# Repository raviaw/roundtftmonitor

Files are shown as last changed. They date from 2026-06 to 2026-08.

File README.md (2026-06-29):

# roundtftmonitor

A desk **PC + Claude usage monitor** on a 1.28″ round ESP32 display
(GUITION **ESP32-2424S012**, ESP32-C3 + GC9A01 + CST816 touch).

Two touch-paged screens:

- **PC** — outer ring = **CPU %**, inner ring = **RAM %**, with the live numbers
  in the middle. Thin outer rings hint the Claude session/week.
- **Claude** — outer ring = **5-hour session %**, inner = **7-day week %**, each
  with a **period-progress bar** and **time-left** label (e.g. `2h left`, `7d left`).
  Thin outer rings hint CPU/RAM.

Colors are green < 60 %, amber 60–85 %, red > 85 %. A small white tick marks each
gauge's 0/start. **Short tap** switches pages; **long-press (>0.6 s)** rotates 90°.

> Heads-up: the Claude session/week figures come from an **undocumented**
> endpoint (see [Claude usage](#claude-usage)); it can change or break without notice.

## How it works

```
 Windows host (host/pc_monitor.py)            ESP32-2424S012 (firmware/monitor)
 ─ reads CPU%/RAM% (psutil)                    ─ parses "key=value" serial lines
 ─ reads Claude session/week % + hours-left    ─ draws two ring-gauge pages
   from the OAuth usage endpoint        ──USB──▶  (touch: tap=page, long=rotate)
 ─ streams one line/sec over COM5 @115200
```

Example line: `cpu=37.5 ram=61.2 sess=26 week=56 sessp=44 weekp=99 sessh=2.8 weekh=8`

## Hardware

| Function | GPIO | | Function | GPIO |
|---|---|---|---|---|
| LCD SCLK | 6 | | Touch SDA (I²C) | 4 |
| LCD MOSI | 7 | | Touch SCL (I²C) | 5 |
| LCD DC | 2 | | Touch INT | 0 |
| LCD CS | 10 | | Touch RST | 1 |
| LCD backlight | 3 | | BOOT button | 9 |
| LCD RST | tied to chip reset | | GPIO 8 | free |

ESP32-C3 (RISC-V @160 MHz, Wi-Fi+BLE5, 4 MB flash, native USB-Serial/JTAG),
GC9A01 240×240 round IPS, CST816D touch (I²C 0x15), no IMU. Full identification:
[`roundtft-hardware.md`](roundtft-hardware.md).

## Build & flash (firmware)

Uses **arduino-cli** + the ESP32 core + **LovyanGFX**.

```sh
FQBN=esp32:esp32:esp32c3:CDCOnBoot=cdc,FlashSize=4M   # CDCOnBoot=cdc is required
arduino-cli compile --fqbn $FQBN --build-path firmware/monitor/build firmware/monitor
arduino-cli upload  -p COM5 --fqbn $FQBN --input-dir firmware/monitor/build firmware/monitor
```

Stop the host agent before flashing (it holds COM5). To restore the as-shipped
GUITION demo: `esptool --port COM5 write-flash 0x0 backup-firmware-stock-4MB.bin`.

## Host agent

```sh
pip install pyserial psutil
python host/pc_monitor.py        # auto-detects the board's COM port
```

CPU%/RAM% come from plain perf counters (no driver, no admin) and update every
second; Claude usage is polled every 5 minutes. To start it automatically at logon,
run `host/install-startup.ps1` once. See [`host/README.md`](host/README.md) for
autostart management and cable/port troubleshooting.

## Claude usage

Session/week % and time-left are read from the **undocumented**
`GET https://api.anthropic.com/api/oauth/usage` using the OAuth token Claude Code
stores in `~/.claude/.credentials.json` (`five_hour` / `seven_day` utilization +
`resets_at`). There is no official API for this; the endpoint may change or break.

## 3D-printed tilt stand

Parametric angled cradle in [`stand/`](stand/) (`stand.scad` → `stand.stl`).
Verify `disc_d` / `disc_t` with calipers first. See [`stand/README.md`](stand/README.md).

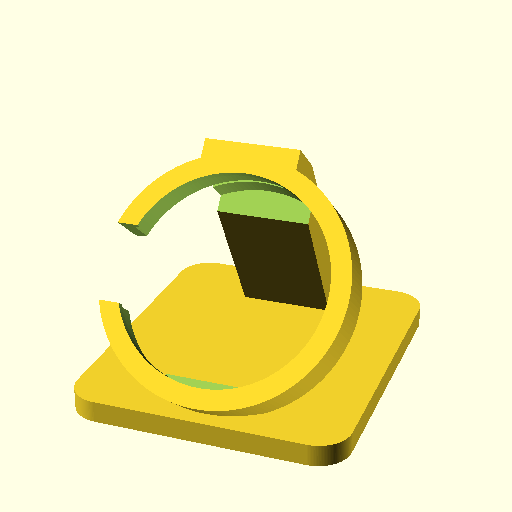
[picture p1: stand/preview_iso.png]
Tilt stand render


## Repo layout

| Path | What |
|---|---|
| `firmware/monitor/` | the monitor sketch (flash this) |
| `firmware/probe/`, `firmware/i2cscan/` | bring-up helpers (pin test, I²C scan) |
| `host/` | Windows serial agent + launcher |
| `stand/` | OpenSCAD tilt stand + renders |
| `PROJECT.md` | design notes, decisions, status |
| `CLAUDE.md` | operational notes & gotchas |
| `roundtft-hardware.md` | chip/board identification |
| `backup-firmware-stock-4MB.bin` | as-shipped firmware (restore point) |

---
🤖 Built with [Claude Code](https://claude.com/claude-code).

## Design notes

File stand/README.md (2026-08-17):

# Desk tilt-stand for the round display

Custom angled cradle for the GUITION **ESP32-2424S012** (1.28" round, ESP32-C3),
sized for the unit **in the plastic shell it ships in** — not a bare PCB.
No off-the-shelf round-board tilt stand exists, so this is a parametric design.

## Files
- `stand.scad` — parametric source (edit + re-render in OpenSCAD)
- `gcode/stand_K1Max_PLA_0.20mm.gcode` — **sliced and ready to print**
- `stand_K1Max_project.3mf` — **the profile, portable**: model + every setting,
  opens ready to slice in Creality Print / Creality Opus / OrcaSlicer
- `stand.3mf` — plain geometry, no settings; 3MF carries units so it imports at
  the right size and orientation
- `slice.sh` + `slicer/*.json` — how that G-code is produced
- `stand.stl` — same mesh, for anything that wants STL
- `verify.py` + `verify.scad` — **run after any change**; ten pass/fail checks
- `gcode_check.py` — bounds-checks sliced G-code and proves the brim is real
- `print_check.py` — build-volume fit, overhang and bed-contact numbers
- `preview_iso.png` / `preview_side.png` / `preview_front.png` — renders
- `fit_check.png` — the shell drawn seated in the cradle (see below)
- `drawing.html` — a single-file drawing sheet: dimensioned section through the
  seat, all views, the dimension schedule and the fit-check results
- `page.tpl.html` + `build_page.py` + `views/` — how `drawing.html` is generated

## The drawing sheet
`drawing.html` is self-contained — every view is inlined as a data URI, because
it gets published as an Artifact and that CSP blocks all external hosts. Rebuild
it with:

```
python build_page.py            # reuse views/
python build_page.py --render   # re-render every view first (~3 min)
```

Both grounds are rendered (`Cornfield` / `Tomorrow Night`) and the page swaps
them with the viewer's theme, so edit `CAMERAS` in `build_page.py` rather than
adding one-off renders.

## What it holds
The shell is a rounded **pebble**, not a cylinder: **45 mm** across at its widest
(its equator), **11 mm** thick, domed glass front, flat-ish back, and the
**USB-C port on the rim**. The black glass is **42 mm**, leaving only **1.5 mm**
of plastic rim — that rim is the entire ledge the cradle has to grip.

> An earlier 40.5 mm figure for the outer edge was wrong and everything derived
> from it was undersized. 45/42 are the measured values.

## What it is
A ring cradle leaning back **38°** toward a seated viewer, on a rearward base
with a back leg. Single solid piece, prints flat on the base.

The seat is a **straight bore plus a front lip**. The shell drops in from the
**back** and stops when its face meets the lip; the backward lean means gravity
presses it onto that lip, so nothing needs to snap or clamp and it still lifts
straight out. About **2.7 mm of the shell stands proud at the back**, which is what
you push on to pop it out.

> A conical seat was tried first and abandoned: where a cone grips depends on how
> the shell's rim curves, which can't be measured off a photo. The lip doesn't
> care — it stops the shell in the same place whatever the rim does.

### The USB-C exits sideways
Not downward. A right-angle plug needs ~10 mm of radial clearance, and at the
bottom of the ring that clearance is below the desk. Out the side it costs
nothing and leaves the load-bearing bottom arc of the ring intact.

Set `port_angle` to move it: `0` = bottom, **`90` = viewer's left (default)**,
`270` = viewer's right. **Rotate the UI in firmware to match.**

## Size
- Footprint **58 × 68 mm** (70 mm overall — the ring's lip overhangs the base
  front by ~1.7 mm), height **~51 mm**
- ~28.8 cm³ (~36 g PLA solid, ~12 g at 3 walls / 15 % infill)
- **Watertight**: 0 naked edges, 0 non-manifold edges

## The tightest fit in the part
There is only **1.5 mm** of plastic rim between the glass (⌀42) and the shell's
outer edge (⌀45), and the front lip has to land inside it. `aperture` = **43.0**
splits that budget:

| | ⌀ | |
|---|---|---|
| Shell outer edge | 45.0 | measured |
| **Front lip bore** | **43.0** | leaves **1.0 mm** of ledge under the shell |
| Black glass | 42.0 | lip stops **0.5 mm** short of it |

FDM prints holes undersize, which moves the lip **toward the glass** and away
from losing grip. So the 0.5 mm is specifically a shrink budget — the ledge only
ever gains. At a pessimistic 0.5 mm of shrink the lip still clears the glass by
0.25 mm and the ledge grows to 1.25 mm.

And the failure is bounded: the **active display is only ⌀32.4**, so the lip sits
**5.3 mm clear of it on radius**. A lip that lands wrong makes the shell rock —
it cannot cover the screen.

`stand.scad` **asserts** `glass_d < aperture < disc_d` and `disc_t > ring_d`, so
a bad edit fails the render instead of quietly printing a cradle that sits on
the screen.

All three seat dimensions are measured and confirmed: `disc_d` 45,
`glass_d` 42, `disc_t` 11 — the last re-checked after the diameter correction.
The only estimated number left anywhere is `rim_r`, which lives inside the fit
check and never reaches the printed part.

**Reading the edge:** glass and rim are both glossy black, so the boundary
hides head-on. Tilt the shell under a light until the glass catches a
reflection and the plastic doesn't; a fingernail dragged inward catches the
step. `drawing.html` shows this drawn, with good/bad sections.

Also worth ten seconds: the **width of your right-angle USB-C plug's moulded
body**. The rim notch is `cable_w` = 16 mm, so up to ~15 mm drops through.

## Changing the lean
Set `tilt` (currently **38°**) and re-render — nothing else needs touching.
`place_z` is *derived* from it, because leaning the cradle moves its lowest
point; a hard-coded height is how the part once ended up below the build plate.
Re-run the fit check afterwards.

## Checking the fit before you print
`stand.scad` can draw a stand-in for the shell seated in the cradle:

```
openscad -D show_pebble=true -o fit_check.png stand.scad
```

The shape of that stand-in depends on `rim_r`, an eyeballed guess at the rim's
corner radius. It affects **the check only, never the printed part**.

The seat was verified by intersecting that stand-in with the model and measuring
the overlap volume — **0.00 mm³**, i.e. pure tangential contact, no clash with
the ring, leg, or base. Worth re-running after any change to the seat or stance.

Measuring caught three real faults that eyeballing renders did not:
- the base slab filled the bottom of the pocket — the seat must be cut *after*
  the base and leg are unioned on, not before;
- the ring's back-bottom edge hung 1.3 mm below the build plate;
- the **base plate floated 2.25 mm off the plate**, leaving the part balanced on
  an 18 × 8 mm bar, because it was lifted by half its thickness as though
  `rrect()` were centred on the origin when it already builds up from it.

That last one is why the bounding box is not enough on its own. Intersect the
model with a thin slab at the bottom and check the volume matches the base
footprint (**3121 mm³** in the lowest 0.8 mm) — a bbox reports `z = 0` just as
happily when a single small bar is all that touches the bed.

## Re-render after editing
```
"E:\dev\openscad\openscad-2021.01\openscad.exe" -o stand.stl stand.scad
```
Or open `stand.scad` in OpenSCAD, F5 to preview / F6 to render, then export STL.
A clean render reports **`Volumes: 2`** — one solid plus the surrounding void,
i.e. a single body.

## Printing

Load **`stand.3mf`** rather than the STL — 3MF carries units, so it lands at the
right size and orientation with nothing to set. It is already base-down and
sitting on z = 0; do not rotate it.

Run `python print_check.py` for the numbers below on the current geometry.

### On the K1 Max
Everything here is comfortably inside the machine — 58 × 70 × 51 mm is 23 % of
the 300³ build volume.

| Setting | Value | Why |
|---|---|---|
| Orientation | as supplied | base-down, no rotation |
| Layer height | 0.2 mm | the 1.8 mm front lip is 9 layers |
| Walls | 3 | the 2.8 mm ring wall is 7 extrusions wide |
| Infill | ~15 % | nothing here is structural |
| **Supports** | **off** | see below |
| **Brim** | **not needed** | 3902 mm² of bed contact |
| **Min layer time** | **8–10 s** | the one setting that matters, see below |

**Supports: don't.** Only **46 mm² of the whole part** leans past 55°, and it is
all one feature — the lead-in chamfer at the top-back of the ring. That chamfer
is cut at 45° to the ring's axis, and because the ring leans 38° it ends up
facing nearly straight down. It will droop slightly. That is harmless: the
chamfer exists purely to let the shell start into the bore, so a soft edge there
costs nothing, and supports would scar the seat instead.

**Minimum layer time is the real K1 Max setting.** The stock profiles are built
for speed, and this part has a tiny cross-section per layer — up in the ring
each layer is a thin arc. At full speed those layers finish before the previous
one has set, and the ring turns out soft and glossy. Setting a minimum layer
time of 8–10 s (or capping speed to ~30 % on the outer wall) fixes it.

**PLA in an enclosed machine:** leave the door and top open, or the chamber
heat-soaks and you get heat creep in the extruder.

### Bed contact
The base makes full contact — 3902 mm², the entire footprint. That was not true
until the base-plate bug above was fixed, when the part balanced on 144 mm² and
genuinely did need a brim.

## Adversarial review — what a second pass found

Run after every dimension was confirmed. Two faults, one usability limit.

**`rim_r` contradicted the measurements.** The fit-check stand-in used an
eyeballed 3.5 mm edge radius, which implies a 38 mm front face — too small to
carry a 42 mm glass. Every interference check had been running against a shape
that cannot exist. `rim_r` is now *derived* as `(disc_d - glass_d)/2` = 1.5 mm.
The seat still measures 0.00 mm³ of interference, and the shell actually stands
**2.71 mm** proud rather than the 1.75 previously quoted.

**`fit` 0.5 was left over from the 40.5 mm era.** On a 45 mm bore it dies at the
pessimistic end of FDM hole shrink: 0.5 mm of shrink leaves *zero* clearance and
the shell will not go in at all. Now **0.8**, which still enters with 0.3 mm to
spare, and the extra 0.4 mm of slop only eats a 1.0 mm ledge.

**It will slide when you swipe it.** At 3 walls / 15 % infill the part is ~12 g,
~42 g with the display in it. Bare PLA on a desk skids at about **31 g** of
finger force; a deliberate swipe is 100–300 g. Silicone feet raise it to ~163 g,
and printing at 40–50 % infill roughly doubles the part's mass again. This is
mass, not geometry — no shape change fixes it.

Checks that came back clean:
- **Tipping** — pressing the screen cannot tip it backwards at *any* force. At
  38° the push's downward component acts on a 54 mm arm to the back edge while
  the backward component only has a 28.9 mm arm; it presses the stand down.
- **Screen clearance** — 5.3 mm radial between the lip and the active area.
- **The USB-C notch** removes 43.7° of ring, but at the side (90°), while the
  in-plane load is carried at the bottom (0°). Bearing arc untouched.
- **Base floor** under the pocket scoop bottoms out at 1.14 mm — 6 layers.
- **Mesh** watertight, single body.

## Cross-check against the published specs

The unit is a stock **ESP32-2424S012C**, so the figures that come from the part
rather than from calipers are worth holding the design against:

| | | |
|---|---|---|
| Bare PCB | 38.5 × 37.0 mm | [espboards](https://www.espboards.dev/esp32/cyd-esp32-2424s012/) |
| **Active display** | **Φ32.4 mm** | cannot vary — it is the 1.28" panel |
| LCD panel outline | ~35.6 × 38.1 mm | standard GC9A01 1.28" module |
| Cased diameter | "about 42 mm ∅" | [CNX Software](https://www.cnx-software.com/2024/08/06/arduino-and-lvgl-compatible-esp32-c3-board-features-a-1-28-inch-round-touchscreen-display-fully-housed-in-a-case/) |

Two useful consequences:

**`active_d` = 32.4 is the one dimension that cannot be mismeasured**, so it
makes the backstop that survives a bad reading on everything else. The render
now asserts `aperture > active_d + 3`.

**The 42 mm glossy front is not the LCD.** The panel outline is only ~35.6 mm,
so the outer few millimetres of that glossy disc are case, not screen. If it
turns out to be *flat* case plastic rather than a domed lens, `aperture` could
drop to ~38 and the ledge would go from 1.0 mm to about 3.5 mm — a much better
grip. Worth a look at the front face before committing.

### ⚠️ The one conflict, and how to settle it
The only published cased diameter is **~42 mm**, but this unit measured **45 mm**
at its widest and **42 mm** across the glossy front. Those reconcile if 45 is the
equator and 42 the front face — consistent with the rounded pebble profile.

But if the true widest is 42, then the 43 mm lip bore is *larger than the shell*
and the display drops straight through the front of the ring.

**Go/no-go, five seconds:** set calipers to **43.0 mm** and try to pass the shell
through.
- **Jams** → 45 is right, print it.
- **Passes** → the 45 reading was wrong and the design needs refitting.

## The sliced G-code

`gcode/stand_K1Max_PLA_0.20mm.gcode` — produced with OrcaSlicer 2.4.2 using
Creality's own **K1 Max (0.4 nozzle)** machine profile, so the start macro is the
real Klipper one (`START_PRINT EXTRUDER_TEMP=215 BED_TEMP=60`) rather than
something hand-written.

| | |
|---|---|
| Time | **1 h 01 m 41 s** |
| Material | **25.1 g** PLA |
| Layers | 251, 0.20 mm (first 0.25), top at 50.65 mm |
| Walls / infill | 3 / 40 % |
| Supports / brim | none / **8 mm outer brim, 0 gap** |
| Bed | Textured PEI, **60 °C** · nozzle **215 / 210 °C** |

Changed from Creality's stock *0.20mm Standard*: walls 2→3, infill 15→40 %
(mass, so it doesn't skid when you swipe it), and the bed type from **Cool Plate
to Textured PEI** — the CLI defaults to Cool Plate, which silently gives you a
35 °C bed on a machine that ships with textured PEI.

Verified rather than assumed: all 69 102 moves fall inside 0–300 mm in X, Y and
Z, centred on the bed at 150, 150, and the brim is really in the toolpaths.
`slice.sh` re-runs both checks every time.

Re-slice with `./slice.sh` (needs OrcaSlicer portable at `E:\dev\orcaslicer`,
override with `ORCA=`).

### It came off the bed — what changed (2026-08-17)

The first print let go mid-job. The missing brim was the visible half; the
temperatures were the real half.

**The bed was running at 45 °C and the nozzle at 200 °C.** `filament.json`
inherits the *generic* PLA library profile, which puts textured PEI at 45 °C —
Creality's own PLA profile says 60 °C / 220 °C. A 45 °C plate barely holds PLA,
and with `close_fan_the_first_x_layers` at 1 the K1's part fan hits 100 % on
layer 2 and peels the corners while the plate is still weak. Nothing in the
slicer UI flags this; it is only visible in the G-code.

| | was | now |
|---|---|---|
| `brim_type` / width / gap | `no_brim` | `outer_only` / 8 mm / 0 |
| `textured_plate_temp` | 45 °C | **60 °C** |
| `nozzle_temperature` (first / rest) | 200 / 200 | **215 / 210** |
| `initial_layer_print_height` | 0.20 | 0.25 |
| `initial_layer_speed` | 60 mm/s | 30 mm/s |
| `initial_layer_infill_speed` | 60 mm/s | 40 mm/s |
| `close_fan_the_first_x_layers` | 1 | 3 |

Cost: about 3 minutes and 0.4 g.

**`outer_brim_only` is not a value OrcaSlicer 2.4.2 accepts.** Setting it did
not error — it fell back to `auto_brim`, auto_brim decided this part didn't need
one, and the re-sliced file came out with no brim and an identical footprint.
The settings comment in the G-code said `brim_type = auto_brim` and the
toolpaths said nothing at all. The value it wants is **`outer_only`**.

That is why `gcode_check.py` now measures the brim out of the toolpaths — it
finds the `;TYPE:Brim` block and checks it stands at least 0.6 × `brim_width`
proud of the first layer on every side — instead of trusting the setting.
(It also parses `G2`/`G3` now. Arc fitting is on, so a large share of this part's
outline was never bounds-checked at all.)

## Slicing it yourself — Creality Print / Opus / Orca

`stand_K1Max_project.3mf` is the profile in portable form: the model **plus every
resolved setting** in `Metadata/project_settings.config`. Creality Print,
Creality Opus, OrcaSlicer and Bambu Studio are all forks of the same slicer, so
opening that file loads the geometry with all of the above already applied — no
preset import, no vendor-folder juggling. Check the plate is Textured PEI and
slice.

Don't confuse it with `stand.3mf`, which is plain geometry and carries no
settings.

If you'd rather keep the profile around for other jobs, import
`slicer/process.json` and `slicer/filament.json` through *File → Import →
Import Configs*. And if the slicer disagrees with any of it, the sliced
`gcode/*.gcode` needs no slicer at all — copy it to the printer.

## Verifying a change

```
python verify.py
```

Ten pass/fail checks, each of which exists because something once got past
without it:

| Check | Why it is there |
|---|---|
| lip clears the glass | the bore twice ended up on the wrong side of it |
| lip still catches the shell | at ⌀42 against a 43 bore the display falls through |
| shell stands proud | otherwise there is no edge to push it back out by |
| clear of the active display | 32.4 mm is the one figure that cannot be mismeasured |
| one solid body | CGAL `Volumes: 2` — one solid plus the void around it |
| sits on the build plate | the ring's back edge once hung 1.31 mm under it |
| fits the printer | 300³ |
| watertight mesh | the leg's stub was coplanar with the ring's front face |
| shell seats without fouling | a cone once drove the shell 1208 mm³ into the ring |
| full base on the bed | the base plate floated 2.25 mm while the bbox read 0 |

That last pair is the point of the file: a bounding box reports `z = 0` just as
happily when a single 18 × 8 mm bar is all that touches the bed.

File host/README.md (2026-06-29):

# host — PC + Claude monitor agent

Streams **CPU%**, **RAM%**, and **Claude session/week usage** to the round display
(**GUITION ESP32-2424S012**) over USB-serial (COM5).

## Requirements
- Python 3 (using `C:\Python314`)
- `pyserial`, `psutil` — install with: `pip install pyserial psutil`
  (already installed to `E:\dev\pip`; the launcher sets `PYTHONPATH` accordingly)

## Run
```
run-monitor.bat            # auto-detect the board's COM port
run-monitor.bat COM5       # or force a port
```
Or directly:
```
set PYTHONPATH=E:\dev\pip
python pc_monitor.py
```

Leave it running; the board shows "WAITING FOR DATA" until lines arrive, then the
gauges track CPU/RAM. If the stream stops, the board holds the last values for up
to 10 s before showing "WAITING FOR DATA" again. Stop with Ctrl+C; it
auto-reconnects if the board resets.

When run from a console the agent prints each line live; under the autostart task
(no console) it only logs connect/error events, so the logfile stays small.

## Cost on the PC
One Python process polling perf counters once/second — negligible CPU, ~20 MB RAM,
no kernel driver, no admin. (CPU/GPU *temperatures* would need LibreHardwareMonitor;
intentionally not used here.)

## Start automatically at logon
Run once from any PowerShell (no admin needed):
```
powershell -ExecutionPolicy Bypass -File install-startup.ps1
```
This registers a scheduled task **`RoundTFT Monitor`** that runs `pythonw.exe`
(no window) at every logon and restarts it if it crashes. Output goes to
`%LOCALAPPDATA%\roundtft-monitor.log`.

| Do this | Command |
|---|---|
| Stop it (e.g. **before flashing** — it holds COM5) | `Stop-ScheduledTask -TaskName 'RoundTFT Monitor'` |
| Start it again | `Start-ScheduledTask -TaskName 'RoundTFT Monitor'` |
| Remove autostart | `powershell -ExecutionPolicy Bypass -File uninstall-startup.ps1` |

The task launches `pythonw.exe` **directly** (so `Stop-ScheduledTask` reliably
terminates it — a wrapper chain would leave an unkillable child). The Python path
`C:\Python314\pythonw.exe` is set in `install-startup.ps1`; the package dir
defaults to `E:\dev\pip` in `pc_monitor.py` (override with the `ROUNDTFT_PIP` env
var). Edit those if your paths differ.

## Troubleshooting

**Board / display shows "WAITING FOR DATA" and the agent logs `board not found
(303A:1001); retrying...`** — Windows isn't seeing the device.

1. **Use a real USB *data* cable, not a charge-only one.** This is the most common
   cause: the screen lights up (it has power) but no COM port appears, because the
   cable has no data wires. Swap to a cable you've actually copied files with.
2. Plug into a USB port directly on the PC (not a hub); reseat the cable.
3. Unplug, wait a few seconds, replug — the ESP32-C3's native USB re-enumerates.

Confirm Windows sees it (it should report `VID_303A`, usually on COM5):
```
Get-PnpDevice -PresentOnly | Where-Object InstanceId -match 'VID_303A'
```
The agent matches by USB VID/PID, **not** a fixed COM number, so it connects
automatically even if Windows assigns a different port.

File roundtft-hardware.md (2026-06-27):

# Round ESP32 display — hardware identification

_Identified 2026-06-26 by reading the chip and flash directly (esptool v5.3.0)._

## What it is
A **GUITION ESP32-C3 round touch LCD board** (1.28" 240×240 round IPS class,
GC9A01-style panel + capacitive touch — touch confirmed by user). Shipped running
GUITION's factory **LVGL "Smart Watch" demo**.

## Chip (read off silicon)
- **ESP32-C3** (QFN32), revision **v0.4**
- Single-core 32-bit **RISC-V @ 160 MHz**
- **Wi-Fi** + **Bluetooth 5 (LE)**
- **4 MB** embedded flash (XMC, manuf 0x46 / dev 0x4016)
- 40 MHz crystal
- Native **USB-Serial/JTAG** (USB is built into the C3 — no CH340/CP210x bridge)
- **MAC 10:b4:1d:20:45:88** (OUI 10:b4:1d = Espressif)

## How it shows up on Windows
- VID `303A` / PID `1001` (Espressif native USB)
- **COM5** = "USB Serial Device" (the CDC port — use this to flash/talk)
- Also a "USB JTAG/serial debug unit" interface (MI_02)
- Composite device serial = the MAC above

## Firmware currently on it
- Built with **Arduino-ESP32 core**, ESP-IDF **v4.4.3**, compiled **Dec 20 2022**
- App-descriptor magic 0xABCD5432 OK; project_name `arduino-lib-builder` (stock Arduino)
- **LVGL** UI — flash contains the stock `I am LVGL_Arduino` banner
- GUITION branding strings: `by GUITION`, `GUITION`, `Powered By`
- Demo screens: Smart Watch face, Lap info, Navigation/Turn Right, Hour forecast,
  Wi-Fi Setting (`Input SSID and password`) — a Wi-Fi-connected smartwatch demo
- Includes ESP HTTP client + httpd (the Wi-Fi config portal)

## Partition table (read from 0x8000)
| label | type | subtype | offset | size |
|---|---|---|---|---|
| nvs | data | 0x02 | 0x09000 | 20 KB |
| otadata  | data | 0x00 | 0x0E000 | 8 KB |
| app0 | app  | 0x10 | 0x10000 | 3072 KB |
| spiffs | data | 0x82 | 0x310000  | 896 KB  |
| coredump | data | 0x03 | 0x3F0000  | 64 KB |

Single-app layout (no OTA app1). 3 MB available for a replacement sketch.

## Model + pinout (confirmed via board docs; verified empirically by probe)
Board is the **GUITION ESP32-2424S012**:
- LCD driver: **GC9A01** (1.28" round 240×240 IPS)
- Touch: **CST816D**, I2C address **0x15**
- No IMU populated

| Function | GPIO | | Function | GPIO |
|---|---|---|---|---|
| LCD SCLK | 6 | | Touch SDA (I2C) | 4 |
| LCD MOSI | 7 | | Touch SCL (I2C) | 5 |
| LCD DC | 2 | | Touch INT | 0 |
| LCD CS | 10 | | Touch RST | 1 |
| LCD BL | 3 | | BOOT button | 9 |
| LCD RST | none (chip reset) | | **GPIO 8** | free |

USB on GPIO 18/19, UART0 on GPIO 20/21. Only **GPIO 8** is spare.

## Notes
- Nothing was erased during identification — esptool only **read** flash + reset.
- To flash: `esptool --port COM5 ...` works directly (native USB, no button combo
  usually needed; hold BOOT + tap RST if it won't connect).

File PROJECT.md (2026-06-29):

# roundtft — PC performance monitor on a round ESP32 display

## Goal
Repurpose the round ESP32 board as a desk **PC performance monitor**.
- Phase 1 metrics: **CPU %** and **RAM %** (zero-driver, lightest on the PC).
- Later: add **Claude usage** and possibly more — protocol is designed to be
  extensible (just add a field + a widget; no rewrite).

## Chosen architecture (decided)
**Wired USB-serial**, because it is both the *lightest on the PC* and the *fastest
to the screen*:
- Host agent on the PC reads only the needed counters and writes one short line
  down **COM5** (USB-CDC). No web server, no network stack, no extra services.
- Firmware on the board parses the line and renders gauges via LovyanGFX.
- CPU%/RAM% come from plain Windows performance counters → no kernel driver,
  no admin. (Temps/GPU would need LibreHardwareMonitor; intentionally skipped.)

Rejected: Wi-Fi+LibreHardwareMonitor (more overhead/jitter) and ESPHome+Home
Assistant (heaviest — needs HA running; slowest refresh).

## The board (confirmed)
**GUITION ESP32-2424S012** — ESP32-C3, 1.28" 240×240 round IPS **GC9A01**,
**CST816D** capacitive touch (I2C 0x15), 4 MB flash, native USB-Serial/JTAG.
Full hardware detail: [roundtft-hardware.md](roundtft-hardware.md).

### Confirmed pinout
| Function | GPIO | | Function | GPIO |
|---|---|---|---|---|
| LCD SCLK | 6 | | Touch SDA (I2C) | 4 |
| LCD MOSI | 7 | | Touch SCL (I2C) | 5 |
| LCD DC | 2 | | Touch INT | 0 |
| LCD CS | 10 | | Touch RST | 1 |
| LCD BL (backlight) | 3 | | BOOT button | 9 |
| LCD RST | none (tied to chip reset) | | **GPIO 8** | free |

Only **GPIO 8** is spare. USB on 18/19, UART0 on 20/21. (Pinout from the
ESP32-2424S012 board docs; being empirically verified by the probe sketch.)

## Toolchain
- **arduino-cli** at `E:\dev\arduino-cli\` (config `arduino-cli.yaml`, data/user dirs there).
- ESP32 Arduino core installed via `core install esp32:esp32`.
- Library: LovyanGFX (GC9A01 driver).
- Board FQBN: `esp32:esp32:esp32c3` with **`CDCOnBoot=cdc`** so `Serial` = USB on COM5.

## Restore the stock GUITION demo anytime
```
esptool --port COM5 write-flash 0x0 backup-firmware-stock-4MB.bin
```
(`backup-firmware-stock-4MB.bin` = full 4 MB dump of the as-shipped firmware.)

## Repo layout
- `backup-firmware-stock-4MB.bin` — as-shipped firmware (do not delete).
- `roundtft-hardware.md` — full chip/flash identification.
- `firmware/probe/probe.ino` — pin-verification probe (backlight blink + GC9A01 test pattern).
- `firmware/monitor/` — (planned) the real CPU/RAM monitor sketch.
- `host/` — (planned) the Windows serial agent that feeds CPU%/RAM%.

## Status
- [x] Identify board + pinout
- [x] Back up stock firmware
- [x] Install arduino-cli + start ESP32 core install
- [x] Write probe sketch
- [x] Compile + flash probe, confirm screen lights up — **CONFIRMED** ("PROBE OK" + sweep, colors correct)
- [x] Build monitor firmware + serial protocol — `firmware/monitor/monitor.ino`
- [x] Build Windows host agent (CPU%/RAM%) — `host/pc_monitor.py` (+ `run-monitor.bat`)
- [x] Flash monitor + run agent — **WORKING** (gauges track live CPU%/RAM%)
- [ ] Add Claude-usage metric (later) — stub at `get_claude_usage()` + EXTENSION POINT in firmware

## Current display
Two pages, **short tap** toggles, **long-press** rotates 90°. The active page is
identified by the center labels (CPU/RAM vs SESS/WEEK).
- **Page 0 (PC):** thick outer ring = CPU%, thick inner ring = RAM%, center
  `CPU%/RAM%`. Two **thin** outer rings hint Claude session/week.
- **Page 1 (Claude):** thick outer = Session (5h)%, thick inner = Week (7d)%,
  center `SESS%/WEEK%`. Two **thin** outer rings hint CPU/RAM.
Colors: green <60, amber 60-85, red >85 (so a near-full red ring = near a limit).
Claude values show `--` if unavailable. The last values are held across a gap for
up to 10 s; after that the board shows "WAITING FOR DATA".

## Claude usage source
Host reads the OAuth token from `~/.claude/.credentials.json` and GETs the
**undocumented** `https://api.anthropic.com/api/oauth/usage` (`five_hour` /
`seven_day` utilization), **once every 5 minutes**. No official API exists; the
endpoint may break without notice. CPU%/RAM% still update every 1 s.

## Sensors / inputs
- **No IMU / gyroscope** — confirmed by I2C scan (`firmware/i2cscan/`): the only
  device on the bus is **0x15 (CST816 touch)**. No 0x68/0x69/0x6A/0x6B.
- **Touch long-press rotates the view 90°**: hold a finger on the glass for
  >0.6 s and the display turns one quarter-turn (cycles through all 4 orientations).
  One step per press — lift before pressing again. Tunable via `LONG_MS` in
  `firmware/monitor/monitor.ino`.

## Day-to-day use
Run `host/run-monitor.bat` (auto-detects the port). For auto-start at logon, run
`host/install-startup.ps1` once (hidden scheduled task). Board keeps the gauges as
long as the agent runs.

## Serial protocol (host -> board)
One line per update, `\n`-terminated, space-separated `key=value` pairs, e.g.:
```
cpu=37.5 ram=61.2
```
Firmware updates known keys and ignores unknown ones, so adding a metric later
(e.g. `claude=...`) needs only a new field on the host + a widget on the board.
Baud 115200 on COM5 (USB-CDC). The board holds the last values across a gap for
up to 10 s; if no line arrives for longer it shows "WAITING FOR DATA".

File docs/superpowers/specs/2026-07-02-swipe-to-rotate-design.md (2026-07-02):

# Swipe-to-rotate gesture — design

**Date:** 2026-07-02
**Status:** approved (approach A), implementing
**File:** `firmware/monitor/monitor.ino` (touch handling only)

## Problem / motivation
Orientation is currently changed by a 0.6–1.5 s **hold** (`handleTouch`). That hold is:
- fragile (a timing band wedged between tap and brightness),
- the prolonged touch we believe **poisons the CST816 baseline** and triggers the
  post-rotate phantom-flip bursts (see commit 2c64e3c), which forced a 2 s lockout,
- one-directional (cycles 0→1→2→3→0 only).

Replace it with a **horizontal swipe**, which is distinct, intuitive, bidirectional,
and immune to phantom center-touches (a phantom jitters in place; it never travels).
Removing the hold also removes the baseline-poisoning trigger.

## Gesture ladder (after)
| Gesture | Detection | Action |
|---|---|---|
| **Swipe (any direction)** | net travel ≥ `SWIPE_MIN_PX` on either axis | rotate 90° (dominant axis → CW/CCW) |
| **Tap** | released < `BRIGHT_MS`, low travel | next page |
| **Hold ≥ `BRIGHT_MS`** | low travel, held past 1.5 s | brightness mode → drag → release saves |

> **On-device finding (revised from horizontal-only):** the trajectory capture showed the
> CST816 tracks swipe motion cleanly (smooth x/y streams), but users naturally swipe
> *vertically* as often as horizontally. Horizontal-only detection dropped those to
> page-changes ("hard to register"). Fixed by accepting a swipe on **either** axis; the
> dominant axis picks CW vs CCW. Measured: real swipes travel 150–200 px, taps 0–8 px,
> phantom peaks ~40 px — so the 50 px bar cleanly separates all three.

The 0.6–1.5 s rotate band and `LONG_MS` are removed. Any non-swipe release before the
brightness threshold is a page tap.

## Detection design
- `readTouchY` → `readTouch(int& sx, int& sy)`: returns the touch point mapped to
  **on-screen** coordinates for the current rotation (both axes, not just vertical),
  so "horizontal" always means horizontal *to the user* regardless of orientation.
  Screen mapping (panel x,y 0..239):
  - rot0: sx=x, sy=y · rot1: sx=y, sy=239−x · rot2: sx=239−x, sy=239−y · rot3: sx=239−y, sy=x
  (sy matches the existing, working `vy` mapping; sx derived from the same convention.)
- Track `tpDownX/Y` at the press edge and `tpLastX/Y` on every good read.
- At the release edge, `dx = tpLastX − tpDownX`, `dy = tpLastY − tpDownY` (net
  displacement — robust to jitter). A swipe is `|dx| ≥ SWIPE_MIN_PX || |dy| ≥
  SWIPE_MIN_PX`; the dominant axis's sign picks CW vs CCW. Classify swipe first,
  else fall through to tap/hold. Constant `SWIPE_CW` flips all directions if it
  feels backwards.

## Tuning
- `SWIPE_MIN_PX = 50`. A deliberate face swipe on the 240 px panel travels 100–200 px;
  a tap < ~15 px; phantom net displacement stays small (jitter doesn't accumulate in
  one direction). 50 px sits with wide margin between tap and swipe.
- Log each rotate as `swipe dx=.. dy=.. -> rotate N` for on-device verification/tuning;
  trim the log once calibrated.

## Lockout
- Swipe-rotate and tap → short `TAP_LOCK_MS` (150 ms lift-off bounce).
- Brightness release (still a long hold) → keep `ROT_LOCK_MS` for baseline recovery.
- The 2 s post-rotate dead-time is gone — rotate is now snappy.

## Risks
- Swipe/tap threshold needs a real-swipe sanity check (logged).
- Direction mapping across rotations must be consistent (flip constant if needed).
- Muscle-memory change from the old hold; net an upgrade.

## Out of scope
Hardware CST816 gesture register (approach B), double-tap (C), on-screen arrow hint
(possible later polish).

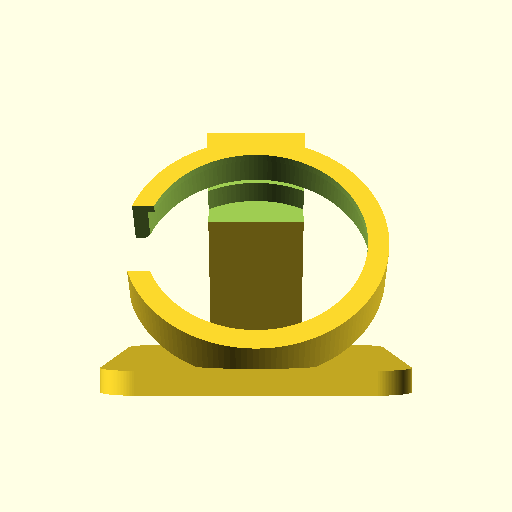
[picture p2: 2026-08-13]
stand/preview_front.png

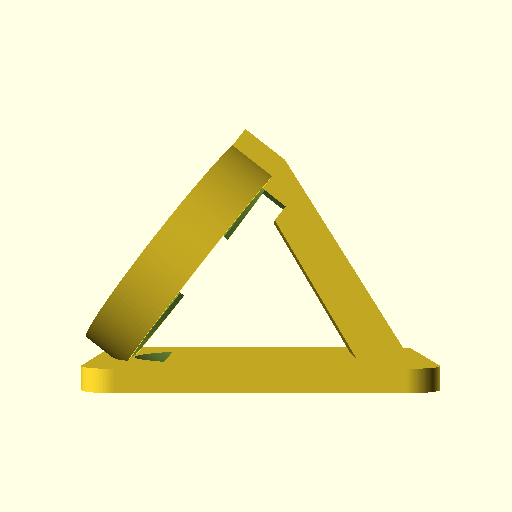
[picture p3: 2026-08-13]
stand/preview_side.png

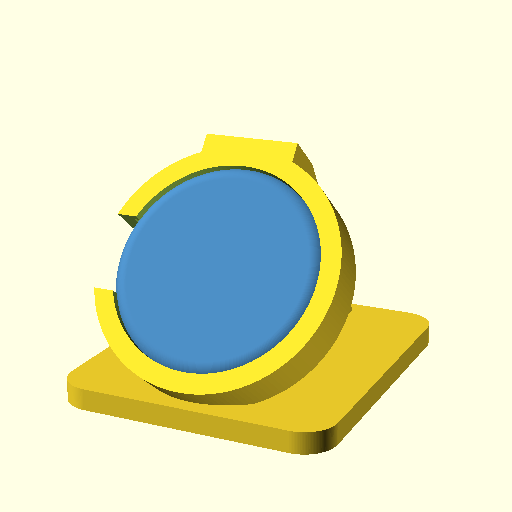
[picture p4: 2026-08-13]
stand/fit_check.png

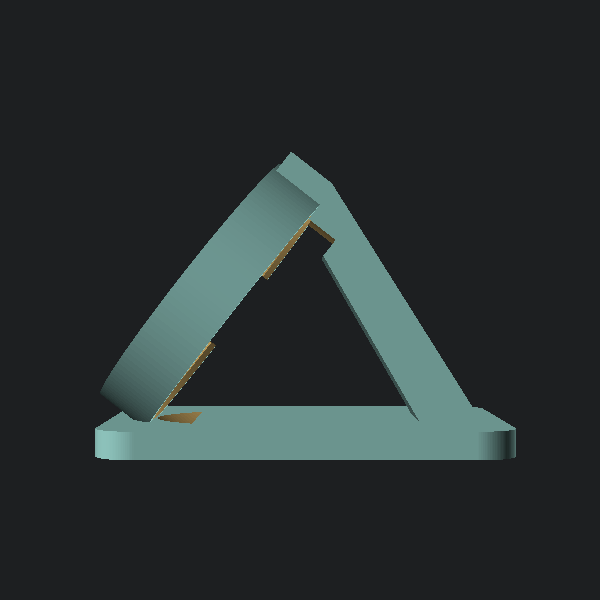
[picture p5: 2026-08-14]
stand/views/side-dark.png

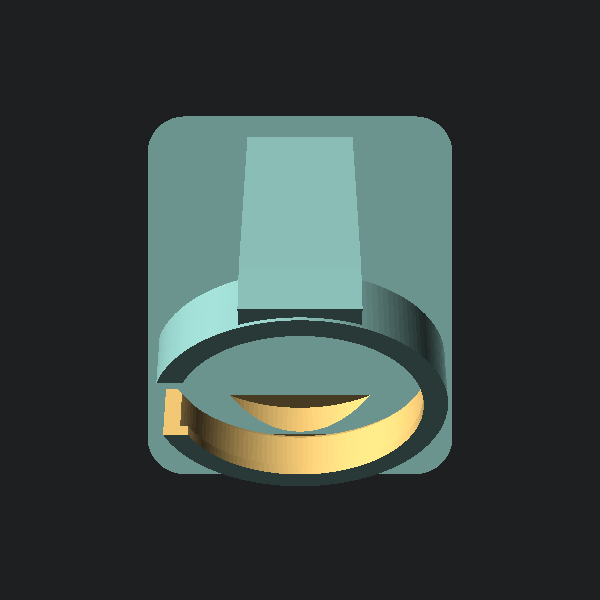
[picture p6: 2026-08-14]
stand/views/top-dark.png

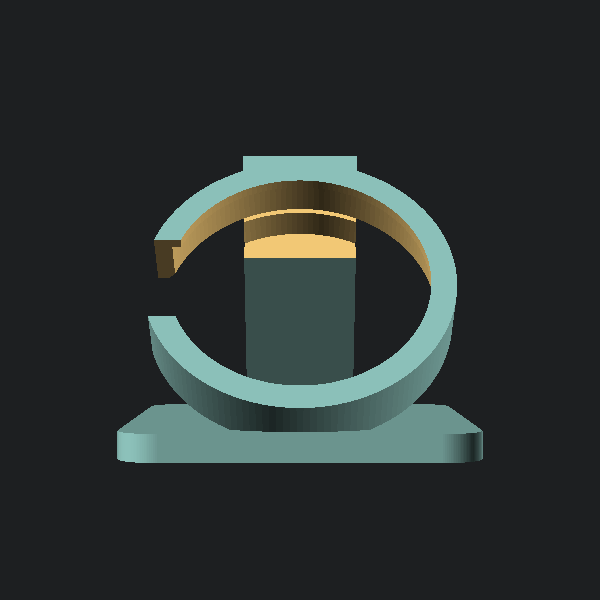
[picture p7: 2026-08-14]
stand/views/front-dark.png

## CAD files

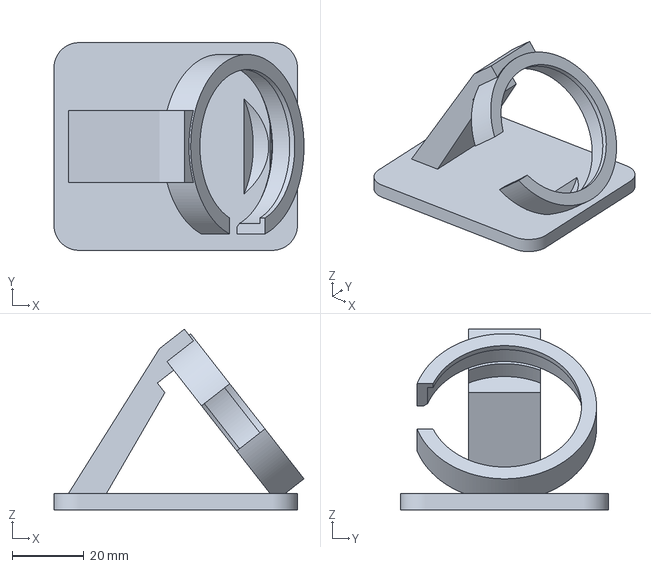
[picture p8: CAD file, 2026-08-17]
stand/stand_K1Max_project.3mf
69.8 x 58.0 x 50.4 mm

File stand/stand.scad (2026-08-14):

// Desk tilt-stand for the GUITION ESP32-2424S012 in its PLASTIC SHELL.
//
// The shell is a rounded "pebble", not a cylinder: 40.5 mm across at its
// equator, 11 mm thick, domed glass front, flat-ish back, USB-C on the RIM.
//
// Seat = straight bore + a front lip. The pebble drops in from the BACK and
// stops when its face meets the lip; the 20 deg backward lean means gravity
// presses it onto that lip, so no snap-fit is needed and it still lifts out.
// (A conical seat was tried first and dropped: where a cone grips depends on
// the rim's curvature, which can't be measured off a photo. The lip doesn't
// care -- it stops the pebble at the same place whatever the rim does.)
//
// Units: mm.  Viewer is at +Y; screen faces +Y. Support & base extend to -Y.

/* ---------- published specs for a stock ESP32-2424S012C ----------
   Fixed by the part, not measurable off one unit. Use them to sanity-check any
   caliper reading before it becomes geometry.
     bare PCB          38.5 x 37.0 mm
     active display    32.4 mm dia      <- cannot vary, it is the 1.28" panel
     LCD panel outline ~35.6 x 38.1 mm
     cased diameter    "about 42 mm" (CNX Software) -- see the NOTE below     */
active_d    = 32.4;

/* ---------- fit parameters (measured off the shell) ---------- */
// NOTE: the only published cased diameter is ~42 mm, while this unit measured
// 45 mm at the widest and 42 mm across the glossy front. Those reconcile if 45
// is the equator and 42 the front face -- but if the true widest is 42, the
// 43 mm lip bore is LARGER than the shell and it drops straight through the
// front of the ring. Gauge it: set calipers to `aperture` and try to pass the
// shell through. It must NOT fit.
disc_d      = 45;    // shell diameter at its widest -- the equator
disc_t      = 11;    // shell thickness front-to-back
glass_d     = 42;    // outermost glossy front area the lip must not sit on

/* ---------- seat ---------- */
// The lip bore must clear the glass and still catch the rim, and there is only
// 1.5 mm of rim to aim at. 43.0 splits it: 0.5 mm clear of the glass on radius,
// 1.0 mm of ledge under the shell. Holes print undersize on FDM, so the 0.5 mm
// glass clearance is the half that must not be spent.
aperture    = 43.0;  // front lip bore. MUST stay between glass_d and disc_d
// Diametral clearance on the bore. 0.5 was carried over from when the shell was
// thought to be 40.5; on a 45 mm bore it dies at the pessimistic end of FDM hole
// shrink -- 0.5 mm of shrink leaves zero and the shell simply will not go in.
// 0.8 still enters with 0.3 mm to spare, and the 0.4 mm of slop it allows only
// eats into a 1.0 mm ledge.
fit         = 0.8;
front_thick = 1.8;   // thickness of the front lip
ring_d      = 10.0;  // ring depth. < disc_t so the back stands proud to grip
wall        = 2.8;   // ring wall thickness
lead_in     = 1.0;   // 45 deg chamfer at the back opening, to start the pebble

bore        = disc_d + fit;

// The lip only works inside this window, and the window is 1.5 mm wide. Fail
// the render rather than quietly print a cradle that sits on the screen.
assert(aperture > glass_d,
       "aperture is inside the glass -- the lip would sit on the screen");
assert(aperture < disc_d,
       "aperture is wider than the shell -- the lip would not catch it at all");
assert(disc_t > ring_d,
       "shell is shallower than the ring -- it would sink in with no edge to grip");
// active_d is the one dimension that cannot vary between units, so it makes the
// only backstop that survives a bad caliper reading on everything else.
assert(aperture > active_d + 3,
       "lip is closing on the 32.4 mm active area -- a measurement is wrong");

/* ---------- USB-C on the rim ---------- */
// The port exits SIDEWAYS, not downward: a right-angle plug needs ~10 mm of
// radial room, and at the bottom that room is below the desk. Out the side it
// costs nothing and leaves the load-bearing bottom arc of the cone intact.
// Rotate the UI in firmware to match. port_angle: 0 = bottom, 90 = viewer's
// left, 270 = viewer's right.
port_angle  = 90;
cable_w     = 16;    // notch width -- clears the right-angle plug's moulded body

/* ---------- stance ---------- */
// Lean back from vertical. The screen's normal rises by this angle, so it aims
// at a seated viewer's eye when they're ~1.4x as far away as they are above it.
tilt        = 38;
merge       = 2.0;   // how far the ring's lowest edge sinks into the base
// Base is sized off the ring: it has to stay wider than the 51.1 mm ring OD or
// the cradle overhangs its own footprint.
base_w      = 58;    // base width
base_d      = 68;    // base depth (front-back)
base_t      = 4.5;   // base thickness
foot_r      = 7;     // base corner radius
leg_w       = 20;    // back-leg width
$fn         = 150;

outer   = bore + 2*wall;
Rb      = outer/2;
base_y  = -(base_d/2) + 14;                  // shift base rearward

// Cradle centre height, DERIVED -- do not hard-code it. Because the ring leans,
// its BACK-bottom edge hangs lowest, at place_z - (Rb*cos(tilt) + ring_d*sin(tilt)).
// This puts that edge `merge` below the base's top face, so the two fuse and
// nothing pokes under the build plate. A hard-coded value is exactly how the
// part once ended up 1.3 mm below the plate after the stance changed.
place_z = base_t - merge + Rb*cos(tilt) + ring_d*sin(tilt);

module rrect(w,d,t,r){
  hull() for(sx=[-1,1], sy=[-1,1])
    translate([sx*(w/2-r), sy*(d/2-r), 0]) cylinder(r=r, h=t);
}

// flat cradle blank: axis Z, screen faces -Z (front), pocket opens toward +Z
module ring_blank(){ cylinder(d=outer, h=ring_d); }

// everything removed to form the seat. Cut LAST, after the base and leg are
// unioned on -- the ring merges into the base, so the base slab would
// otherwise fill the bottom of the pocket and the shell would foul on it.
module seat_cuts(){
  translate([0,0,-1])          cylinder(d=aperture, h=ring_d+2);  // window
  // Pocket. Runs the FULL depth of the shell plus margin, not just the ring
  // depth: the shell stands ~2 mm proud of the back face, and the leg's hull
  // sweeps past there -- without this it clips the shell's back edge.
  translate([0,0,front_thick]) cylinder(d=bore, h=disc_t + 3);
  // 45 deg lead-in at the back opening so the pebble starts square
  translate([0,0,ring_d - lead_in])
    cylinder(d1=bore, d2=bore + 2*lead_in, h=lead_in + 0.01);
  // rim notch for the USB-C plug, swung round to port_angle
  rotate([0,0,port_angle])
    translate([-cable_w/2, -Rb-1, -1])
      cube([cable_w, Rb+1 - (aperture/2 - 4), ring_d+2]);
}

// place flat cradle into the leaned pose (screen -> +Y & up)
module place(){ translate([0,0,place_z]) rotate([90+tilt,0,0]) children(); }

// stub biting into the ring's upper wall, held clear of the pocket bore so it
// survives seat_cuts() and never fouls the shell going in
// Inset from both ring faces on purpose. Flush at z=0 makes the stub's front
// face coplanar with the ring's, and coplanar faces meet in non-manifold edges
// -- four of them, at the top of the leg. Slicers mostly paper over that; the
// fix costs nothing and keeps the mesh clean.
module neck(){
  translate([-leg_w/2, bore/2 + 0.4, 0.6]) cube([leg_w, 4.5, ring_d - 1.2]);
}

// base plate (rearward). rrect() already builds up from z=0, so this sits ON
// the build plate -- do NOT lift it by base_t/2 as if rrect were centred, or
// the whole plate floats and the part balances on the back leg's bar alone.
module base_plate(){
  translate([0, base_y, 0]) rrect(base_w, base_d, base_t, foot_r);
}

// back leg: smooth hull from a base-back bar up to the ring's upper back
module back_leg(){
  hull(){
    translate([-leg_w/2, base_y - base_d/2 + 4, 0]) cube([leg_w, 8, base_t]);
    place() neck();
  }
}

module stand(){
  difference(){
    union(){ place() ring_blank(); base_plate(); back_leg(); }
    place() seat_cuts();
  }
}

/* ---------- fit check (never part of the STL) ----------
   openscad -D show_pebble=true -D section=true -o fit_check.png stand.scad   */
show_pebble = false;   // draw a stand-in for the shell, seated in the cone
section     = false;   // slice the model in half to see the seat

// stand-in for the shell: disc_d at the equator, disc_t thick, rounded rim.
//
// rim_r is DERIVED, not eyeballed. The glass sits on the front face, so the
// face must be at least glass_d across; the widest point is disc_d; therefore
// the edge cannot pull in by more than half the difference. Guessing 3.5 here
// implied a 38 mm front face carrying a 42 mm glass, which is impossible -- and
// every interference check ran against that impossible shape.
rim_r = (disc_d - glass_d) / 2;
module pebble(){
  rotate_extrude($fn=120)
    hull(){
      translate([disc_d/2 - rim_r, rim_r])          circle(r=rim_r);
      translate([disc_d/2 - rim_r, disc_t - rim_r]) circle(r=rim_r);
      square([0.01, disc_t]);
    }
}
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

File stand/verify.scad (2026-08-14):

// Geometry probes for verify.py. Not part of the printed model.
//
//   openscad -D mode=\"interference\" -o out.stl verify.scad
//   openscad -D mode=\"slab\" -D slab_z=0 -o out.stl verify.scad
//
// `use` imports the modules without running stand.scad's own top-level output.
use <stand.scad>

mode   = "interference";
slab_z = 0;      // height of the bottom slice, mm
slab_t = 0.8;    // its thickness, mm

// Where the shell sits versus where the cradle is. Should be empty: the two
// touch tangentially and nothing more.
if (mode == "interference")
  intersection() { stand(); seated_pebble(); }

// A thin slice at the bottom. Its area is what actually touches the bed -- a
// bounding box says z=0 just as happily when one small bar is all that lands.
if (mode == "slab")
  intersection() {
    stand();
    translate([-200, -200, slab_z]) cube([400, 400, slab_t]);
  }

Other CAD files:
stand/stand.3mf
stand/stand.stl

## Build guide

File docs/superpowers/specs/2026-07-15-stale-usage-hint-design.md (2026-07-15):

# Stale-usage hint on the SESSION/WEEK page

## Problem

The Claude usage (session/week %) readout goes dark for long stretches. Root
cause (confirmed 2026-07-15 from `roundtft-monitor.log`): the host cannot refresh
the OAuth token itself — it only *reads* `accessToken` from `.credentials.json`
and depends on Claude Code (or the desktop app) being alive to keep it fresh.
When nothing refreshes it (overnight / long idle), the access token dies, every
usage probe fails (a clean ~4×`401` then ~4×`429` cycle — 429 is the shared
rate-limiter refusing before auth; 401 is the dead token), and the board grays
the numbers with no explanation. It self-heals the moment Claude Code refreshes
the token (observed: 14 h of failures ended at a success the instant a session
resumed).

We are **not** adding self-refresh (risk: rotating the refresh token could break
Claude Code's own login). Instead: make the grayed-out state *actionable*.

## Change (firmware-only, `firmware/monitor/monitor.ino`)

No host change; the token flow is untouched. Reuse the existing staleness
signal: `usageage` > `USAGE_STALE_SEC` (900 s) → `!usageFresh`.

On **page 1 (SESSION/WEEK)** only, when we have usage values but they are stale,
`drawCenter` renders a compact "stale card" in the 104×104 center sprite instead
of the normal big-number + period-bar layout:

- Six Font2 lines, ~17 px pitch (fits 104 px, no overlap):
  1. `SESSION` (label gray)
  2. `NN%`     (last session value, **gray** — frozen reading stays obvious)
  3. `WEEK`    (label gray)
  4. `NN%`     (last week value, gray)
  5. `OPEN CLAUDE` (**amber** `0xFD40`) — the fix
  6. `STALE Nh` / `STALE Nm` (amber) — how long it's been frozen
- Period bars and history backdrop are suppressed in this state (both are
  meaningless once the values are frozen).

Rings on page 1 already gray when stale (`sFresh`/`wFresh` == false) — unchanged.
Pages 0 and 2 are unchanged (still just gray); the actionable text lives on the
dedicated usage page.

### Why "OPEN CLAUDE" is correct for both 401 and 429

Even in the 429 stretches the blocker is the dead token; recovery came from the
refresh, not from the rate limit clearing. So the remedy is the same regardless
of the last error code — no need for the host to distinguish them, hence no
protocol change.

### Age formatting

From `usageAgeTarget` (seconds): `< 5400 s` → `STALE %dm` (rounded minutes),
else `STALE %dh` (rounded hours).

## Implementation notes

- Add `static const uint16_t AMBER = 0xFD40;` (= `color565(255,170,0)`, the same
  amber as `zoneColor`'s mid band).
- Extend `drawCenter(...)` with two trailing optional params
  `const char* hint1=nullptr, const char* hint2=nullptr`. When `hint1` is set
  (and not `waiting`), draw the stale card branch; otherwise the existing layout.
- In the `page == 1` render path, when `(sOk || wOk) && !usageFresh`, build the
  age string and call `drawCenter(..., "OPEN CLAUDE", ageStr)`; else call as today.
- `waiting` still takes precedence inside `drawCenter` (shows WAITING FOR DATA).

## Out of scope

- Host token self-refresh (deferred; carries login-corruption risk).
- Distinguishing 401 vs 429 on the display.

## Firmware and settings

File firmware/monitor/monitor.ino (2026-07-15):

// PC + Claude monitor for GUITION ESP32-2424S012 (ESP32-C3 + 1.28" round GC9A01)
// Lines over USB-serial (COM5 @115200), '\n' terminated:
//   cpu=37.5 ram=61.2 sess=26 week=56 sessp=44 weekp=99 sessh=2.8 weekh=8 usageage=42
//   cpu/ram=PC%, sess/week=Claude session/week %, sessp/weekp=period elapsed %,
//   sessh/weekh=hours left in each window. usageage=sec since usage was last fetched
//   OK (grays sess/week when stale; absent until the first success). Unknown keys ignored.
//   proc=name:memGB:cpu%|name:memGB:cpu%|...  top-7 processes by memory (own line).
//
// UI: short TAP cycles page (Page0 CPU/RAM, Page1 Session/Week + period bars,
//     Page2 top-7 processes: diverging bars, memory left / CPU right, name in the
//     middle, biggest-memory process centered then alternating below/above).
//     Swipe (any direction) rotates orientation 90 deg; hold past 1.5s enters
//     brightness mode -- drag up/down to set the backlight (saved to NVS).
//     White tick marks each gauge's 0/start (in the ring gap, so it never flickers).
//
// Rendering: rings drawn directly; center text+bars via a small sprite. (Full-
// screen double-buffering was tried and would not display on this panel.)
//
// Pinout: LCD SCLK=6 MOSI=7 DC=2 CS=10 RST=none BL=3 · Touch CST816 @0x15 SDA=4 SCL=5 INT=0 RST=1
// FQBN: esp32:esp32:esp32c3:CDCOnBoot=cdc,FlashSize=4M

#include <LovyanGFX.hpp>
#include <Wire.h>
#include <Preferences.h>

class LGFX : public lgfx::LGFX_Device {
  lgfx::Panel_GC9A01 _panel; lgfx::Bus_SPI _bus;
public:
  LGFX() {
    { auto c = _bus.config();
      c.spi_host = SPI2_HOST; c.spi_mode = 0; c.freq_write = 40000000; c.freq_read = 16000000;
      c.pin_sclk = 6; c.pin_mosi = 7; c.pin_miso = -1; c.pin_dc = 2;
      _bus.config(c); _panel.setBus(&_bus); }
    { auto c = _panel.config();
      c.pin_cs = 10; c.pin_rst = -1; c.pin_busy = -1;
      c.panel_width = 240; c.panel_height = 240; c.invert = true; c.rgb_order = false;
      _panel.config(c); }
    setPanel(&_panel);
  }
};

LGFX tft;
static LGFX_Sprite center(&tft);      // small canvas for the center readout (pages 0/1)
static LGFX_Sprite chart(&tft);       // larger canvas for the process bars (page 2)
static const int CHART_SZ = 154;      // fits inside the thin rings (corner r ~109 < 113)

static const int PIN_BL = 3;
static const int CX = 120, CY = 120;

static const int OUT_R0 = 96,  OUT_R1 = 110;   // outer thick ring (this page, metric 1)
static const int IN_R0  = 76,  IN_R1  = 90;     // inner thick ring (this page, metric 2)
static const int TA_R0  = 117, TA_R1  = 119;    // outer thin ring (other page, metric 1)
static const int TB_R0  = 113, TB_R1  = 115;    // 2nd thin ring   (other page, metric 2)
static const int TICK_R0 = 91, TICK_R1 = 95;    // zero tick lives in the ring gap
static const float START_DEG = 0.0f;

static const int TP_SDA = 4, TP_SCL = 5, TP_INT = 0, TP_RST = 1;
static const uint8_t CST816_ADDR = 0x15;
static const uint32_t BRIGHT_MS = 1500;   // hold past this -> brightness mode
static const uint32_t DEBOUNCE_MS = 40;   // raw touch must hold this long to count
static const int      SWIPE_MIN_PX = 50;  // net travel (either axis) that counts as a rotate swipe
static const bool     SWIPE_CW = true;    // flip if swipes rotate the wrong way
static const uint32_t GESTURE_LOCK_MS = 150;  // ignore contact this long after any gesture: the finger
                                              // rolling off the convex round glass can re-graze on lift-off
uint8_t rotation = 3, page = 0;   // default = three long-presses (270 deg) from 0
bool tpWasDown = false;                    // debounced finger-down state
uint32_t tpPressStart = 0;
int tpLastX = 0, tpLastY = 0;              // last good touch point, on-screen coords
int tpDownX = 0, tpDownY = 0;              // touch point at the press edge (swipe origin)
uint32_t gestureLockUntil = 0;             // suppress new presses until this time

// Backlight (GPIO3) PWM brightness, persisted to NVS flash across reboots.
Preferences prefs;
const uint8_t BL_MIN = 64;        // readable floor: a stray hold once saved ~5% and blanked the screen;
                                  // boot clamps the restored level up to this, so it can never go dark
uint8_t blLevel = 255;            // current duty 0..255
bool brightMode = false;          // adjusting brightness (overlay shown)
int baseY = 0; uint8_t baseLevel = 255;   // touch-Y and level at mode entry
int lastShownLevel = -1;          // last level the overlay was drawn at (-1 = redraw)

float cpuTarget=0, ramTarget=0, sessTarget=0, weekTarget=0;
float cpuDisp=0,  ramDisp=0,  sessDisp=0,  weekDisp=0;
bool sessHave=false, weekHave=false;
float sesspTarget=-1, weekpTarget=-1, sesshVal=-1, weekhVal=-1;
float usageAgeTarget=-1;   // sec since the host last *successfully* fetched usage (-1 = unknown / old host)
// Gray the session/week readouts once usage is this stale. The host polls every
// 5 min on success, so usageage sawtooths 0..~300 when healthy; 900 = 3 missed
// polls = a real outage (429/401 storm), not a single blip. Tune vs host USAGE_REFRESH.
static const float USAGE_STALE_SEC = 900;
uint32_t lastData = 0;
bool everConnected = false;
String inbuf;

// Top-7 processes for Page2 (filled by the "proc=" line; held until replaced).
static const int PROC_MAX = 7;
char  procName[PROC_MAX][16];     // up to 12-char names + NUL
float procMem[PROC_MAX], procCpu[PROC_MAX];
int   procCount = 0;

// Recent CPU/RAM history for the faint backdrop behind the page-0 readout.
// One sample pushed per data line (~1/s); newest drawn at the right edge.
static const int HIST_N = 104;            // == center sprite width -> one column/px
uint8_t cpuHist[HIST_N], ramHist[HIST_N];
int histHead = 0, histCount = 0;          // ring buffer: histHead = next write slot
void pushHist(uint8_t c, uint8_t r) {
  cpuHist[histHead] = c; ramHist[histHead] = r;
  histHead = (histHead + 1) % HIST_N;
  if (histCount < HIST_N) histCount++;
}

// Claude usage (session/week) history for the page-1 backdrop. The value only
// changes every ~15 min, so sample it on a slow 5-min cadence: 104 samples then
// span ~8.7 h (a full session window and a recent slice of the week).
uint8_t sessHist[HIST_N], weekHist[HIST_N];
int usageHead = 0, usageCount = 0;
uint32_t lastUsagePush = 0;
static const uint32_t USAGE_HIST_MS = 300000;   // 5 min between usage samples
void pushUsageHist(uint8_t s, uint8_t w) {
  sessHist[usageHead] = s; weekHist[usageHead] = w;
  usageHead = (usageHead + 1) % HIST_N;
  if (usageCount < HIST_N) usageCount++;
}

uint16_t zoneColor(float v) {
  if (v < 60) return tft.color565(0, 200, 90);
  if (v < 85) return tft.color565(255, 170, 0);
  return tft.color565(255, 60, 60);
}
static const uint16_t GRAY = 0x528A;
static const uint16_t AMBER = 0xFD40;   // color565(255,170,0); == zoneColor's mid band

// "name:mem:cpu|name:mem:cpu|..." -> the proc* arrays (already past "proc=").
void parseProc(const String& s) {
  int n = 0, i = 0;
  while (i < (int)s.length() && n < PROC_MAX) {
    int bar = s.indexOf('|', i); if (bar < 0) bar = s.length();
    String item = s.substring(i, bar);
    int c1 = item.indexOf(':'); int c2 = (c1 >= 0) ? item.indexOf(':', c1 + 1) : -1;
    if (c1 > 0 && c2 > c1) {
      item.substring(0, c1).toCharArray(procName[n], sizeof(procName[n]));
      procMem[n] = item.substring(c1 + 1, c2).toFloat();
      procCpu[n] = item.substring(c2 + 1).toFloat();
      n++;
    }
    i = bar + 1;
  }
  procCount = n;
  lastData = millis(); everConnected = true;
}

void parseLine(const String& line) {
  if (line.startsWith("proc=")) { parseProc(line.substring(5)); return; }
  int i = 0;
  while (i < (int)line.length()) {
    int sp = line.indexOf(' ', i); if (sp < 0) sp = line.length();
    String tok = line.substring(i, sp); int eq = tok.indexOf('=');
    if (eq > 0) {
      String k = tok.substring(0, eq); float v = tok.substring(eq + 1).toFloat();
      if      (k == "cpu")   cpuTarget  = constrain(v, 0, 100);
      else if (k == "ram")   ramTarget  = constrain(v, 0, 100);
      else if (k == "sess")  { sessTarget = constrain(v, 0, 100); sessHave = true; }
      else if (k == "week")  { weekTarget = constrain(v, 0, 100); weekHave = true; }
      else if (k == "sessp") sesspTarget = constrain(v, 0, 100);
      else if (k == "weekp") weekpTarget = constrain(v, 0, 100);
      else if (k == "sessh") sesshVal = v;
      else if (k == "weekh") weekhVal = v;
      else if (k == "usageage") usageAgeTarget = v;
    }
    i = sp + 1;
  }
  pushHist((uint8_t)round(cpuTarget), (uint8_t)round(ramTarget));   // feed the history backdrop
  lastData = millis(); everConnected = true;
}

void readSerial() {
  while (Serial.available()) {
    char c = Serial.read();
    if (c == '\n') { if (inbuf.length()) parseLine(inbuf); inbuf = ""; }
    else if (c != '\r') { inbuf += c; if (inbuf.length() > 300) inbuf = ""; }
  }
}

void touchReset() {
  pinMode(TP_RST, OUTPUT);
  digitalWrite(TP_RST, LOW);  delay(20);
  digitalWrite(TP_RST, HIGH); delay(120);
}
void cst816Write(uint8_t reg, uint8_t val) {
  Wire.beginTransmission(CST816_ADDR); Wire.write(reg); Wire.write(val); Wire.endTransmission();
}
// Read the first touch point; returns whether a finger is down and, if so, the
// touch position mapped to on-screen coordinates (sx,sy) for the current rotation,
// so "horizontal"/"vertical" always mean the same to the user regardless of orientation.
bool readTouch(int& sx, int& sy) {
  Wire.beginTransmission(CST816_ADDR); Wire.write(0x02);
  if (Wire.endTransmission(false) != 0) return false;
  if (Wire.requestFrom((int)CST816_ADDR, 5) != 5) return false;
  uint8_t st = Wire.read();
  uint8_t xh = Wire.read(), xl = Wire.read(), yh = Wire.read(), yl = Wire.read();
  if ((st & 0x0F) == 0) return false;
  int x = ((xh & 0x0F) << 8) | xl;
  int y = ((yh & 0x0F) << 8) | yl;
  switch (rotation & 0x03) {            // map raw panel axes to on-screen (sx,sy)
    case 0:  sx = x;       sy = y;       break;
    case 1:  sx = y;       sy = 239 - x; break;
    case 2:  sx = 239 - x; sy = 239 - y; break;
    default: sx = 239 - y; sy = x;       break;   // case 3
  }
  return true;
}

void setBrightness(int lvl) {
  if (lvl < BL_MIN) lvl = BL_MIN; if (lvl > 255) lvl = 255;
  blLevel = (uint8_t)lvl; ledcWrite(PIN_BL, blLevel);
}

// Gestures: SWIPE in any direction = rotate 90 (dominant axis picks CW/CCW); short TAP = next
// page; HOLD past 1.5s = brightness mode -> drag up/down to adjust (overlay shown), release saves.
// A swipe needs real travel (>=SWIPE_MIN_PX) to separate it from a stationary tap.
void handleTouch() {
  int sx = 0, sy = 0;
  bool raw = readTouch(sx, sy);              // idle reads return "no finger" cleanly
  if (raw) { tpLastX = sx; tpLastY = sy; }           // keep last good point

  // Debounce: even a real edge can straddle a mid-update read, so only let the
  // debounced state flip after the raw reading holds for DEBOUNCE_MS -- a
  // single-sample glitch never becomes a spurious edge.
  static bool rawPrev = false;
  static uint32_t rawSince = 0;
  if (raw != rawPrev) { rawPrev = raw; rawSince = millis(); }
  bool down = tpWasDown;                              // hold state until raw is stable
  if (millis() - rawSince >= DEBOUNCE_MS) down = raw;

  // Lockout: ignore contact for a short window after a gesture, so the finger rolling off
  // the convex round glass on lift-off can't re-graze into a second spurious gesture.
  if ((int32_t)(millis() - gestureLockUntil) < 0) down = false;

  if (down && !tpWasDown) {                           // press edge
    tpPressStart = millis(); brightMode = false;
    tpDownX = tpLastX; tpDownY = tpLastY;             // remember where a swipe started
  }
  uint32_t held = millis() - tpPressStart;

  if (down && !brightMode && held > BRIGHT_MS) {     // enter brightness mode
    brightMode = true; baseY = tpLastY; baseLevel = blLevel; lastShownLevel = -1;
  }
  if (down && brightMode) {                          // up = brighter (~1.5/px)
    setBrightness((int)baseLevel + (baseY - tpLastY) * 3 / 2);
  }

  if (!down && tpWasDown) {                           // release edge
    int dx = tpLastX - tpDownX, dy = tpLastY - tpDownY;   // net travel since press (jitter-robust)
    int adx = abs(dx), ady = abs(dy);
    if (brightMode) {
      prefs.putUChar("bl", blLevel);                 // persist chosen level
      brightMode = false; tft.fillScreen(TFT_BLACK);
      Serial.printf("brightness -> %u\n", blLevel);
      gestureLockUntil = millis() + GESTURE_LOCK_MS;
    } else if (adx >= SWIPE_MIN_PX || ady >= SWIPE_MIN_PX) {   // a swipe in ANY direction -> rotate
      int dir = (adx >= ady) ? (dx > 0 ? 1 : -1)     // dominant axis picks CW vs CCW:
                             : (dy > 0 ? 1 : -1);     // right/down = one way, left/up = the other
      if (!SWIPE_CW) dir = -dir;
      rotation = (rotation + (dir > 0 ? 1 : 3)) & 0x03;   // +1 = CW, +3 = one step CCW
      tft.setRotation(rotation); tft.fillScreen(TFT_BLACK);
      prefs.putUChar("rot", rotation);               // persist orientation
      Serial.printf("swipe dx=%d dy=%d -> rotate %d\n", dx, dy, rotation);
      gestureLockUntil = millis() + GESTURE_LOCK_MS;
    } else {                                          // low travel -> tap = next page
      page = (page + 1) % 3; tft.fillScreen(TFT_BLACK);
      Serial.printf("page -> %d\n", page);
      gestureLockUntil = millis() + GESTURE_LOCK_MS;
    }
  }
  tpWasDown = down;
}

void drawRing(int r0, int r1, float val, uint16_t col) {
  float sweep = 360.0f * (val / 100.0f); if (sweep > 359.9f) sweep = 359.9f;
  tft.fillArc(CX, CY, r0, r1, START_DEG + sweep, START_DEG + 360.0f, tft.color565(35, 35, 40));
  if (sweep > 0.1f) tft.fillArc(CX, CY, r0, r1, START_DEG, START_DEG + sweep, col);
}
// thin zero tick in the inter-ring gap -> never overpainted, so it can't flicker
void drawStartTick() {
  tft.fillArc(CX, CY, TICK_R0, TICK_R1, START_DEG - 1.5f, START_DEG + 1.5f, TFT_WHITE);
}

void drawBar(int y, float frac, float hours) {       // inside the center sprite
  int bw = 40, bh = 3;
  // build the "Nh"/"Nd" hours-left label and measure it, so the bar+label group
  // can be centered as a unit
  String t = "";
  int tw = 0;
  if (hours >= 0) {
    t = ((hours >= 48) ? String((int)round(hours / 24.0)) + "d"
                       : String((int)round(hours)) + "h") + " left";
    center.setFont(&fonts::Font0);
    tw = center.textWidth(t);
  }
  int gap = t.length() ? 5 : 0;
  int total = bw + gap + tw;
  int bx = center.width() / 2 - total / 2;          // center the whole group
  center.fillRect(bx, y, bw, bh, tft.color565(55, 55, 65));
  int fw = (int)round(bw * constrain(frac, 0, 100) / 100.0);
  if (fw > 0) center.fillRect(bx, y, fw, bh, TFT_WHITE);
  if (t.length()) {
    center.setFont(&fonts::Font0); center.setTextDatum(middle_left);
    center.setTextColor(tft.color565(150, 150, 160), TFT_BLACK);
    center.drawString(t, bx + bw + gap, y + 1);
  }
}

// Dim zone color (~22% brightness over black == the requested "20% opacity").
uint16_t histColor(int v) {
  int r, g, b;
  if      (v < 60) { r = 0;   g = 200; b = 90; }
  else if (v < 85) { r = 255; g = 170; b = 0;  }
  else             { r = 255; g = 60;  b = 60; }
  const float f = 0.22f;
  return tft.color565((int)(r * f), (int)(g * f), (int)(b * f));
}

// Faint history backdrop inside the center sprite: top metric in the top half
// (baseline mid, growing up), bottom metric in the bottom half (baseline bottom,
// growing up). Newest sample at the right edge; the sprite is already black-cleared
// so gaps stay black. kind 0 = CPU/RAM (per-second), 1 = session/week (5-min).
void drawHistBackdrop(int kind) {
  uint8_t *topA, *botA; int head, count;
  if (kind == 1) { topA = sessHist; botA = weekHist; head = usageHead; count = usageCount; }
  else           { topA = cpuHist;  botA = ramHist;  head = histHead;  count = histCount; }
  const int w = center.width();                          // 104
  const int topBase = 50, topH = 49;                     // top metric: y 1..50
  const int botBase = center.height() - 1, botH = 50;    // bottom metric: y 53..103
  for (int k = 0; k < count; k++) {
    int x = w - 1 - k; if (x < 0) break;                 // newest at the right edge
    int idx = ((head - 1 - k) % HIST_N + HIST_N) % HIST_N;
    int tv = topA[idx], bv = botA[idx];
    int th = tv * topH / 100, bh = bv * botH / 100;
    if (th > 0) center.drawFastVLine(x, topBase - th, th, histColor(tv));
    if (bh > 0) center.drawFastVLine(x, botBase - bh, bh, histColor(bv));
  }
}

// One big Font4 percentage centered at (cx,cy). halo=true draws a 1px dark outline
// then the colored value on a transparent bg, so it stays legible over the history
// backdrop; halo=false is the plain opaque-bg draw used on the other pages.
void drawValue(int cx, int cy, bool ok, bool stale, float v, bool halo) {
  String s = ok ? String((int)round(v)) + "%" : "--";
  uint16_t col = (ok && !stale) ? zoneColor(v) : GRAY;
  center.setFont(&fonts::Font4);
  if (halo) {
    center.setTextColor(TFT_BLACK);
    center.drawString(s, cx - 1, cy); center.drawString(s, cx + 1, cy);
    center.drawString(s, cx, cy - 1); center.drawString(s, cx, cy + 1);
    center.setTextColor(col);
    center.drawString(s, cx, cy);
  } else {
    center.setTextColor(col, TFT_BLACK);
    center.drawString(s, cx, cy);
  }
}
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
void loop() {
  readSerial();
  handleTouch();
  // Hold the last received values for up to 10s across a gap (unsigned subtraction
  // is millis()-rollover safe), then fall back to the waiting screen.
  bool waiting = !everConnected || (millis() - lastData > 10000);

  // Sample Claude usage into the page-1 history backdrop: once as soon as data is
  // present, then every 5 min (the value only refreshes ~every 15 min host-side).
  if (sessHave && weekHave && !waiting &&
      (usageCount == 0 || millis() - lastUsagePush >= USAGE_HIST_MS)) {
    lastUsagePush = millis();
    pushUsageHist((uint8_t)round(sessTarget), (uint8_t)round(weekTarget));
  }

  float k = 0.18f;
  cpuDisp  += ((waiting ? 0 : cpuTarget)  - cpuDisp)  * k;
  ramDisp  += ((waiting ? 0 : ramTarget)  - ramDisp)  * k;
  sessDisp += ((waiting ? 0 : sessTarget) - sessDisp) * k;
  weekDisp += ((waiting ? 0 : weekTarget) - weekDisp) * k;

  static uint32_t lastFrame = 0;
  if (millis() - lastFrame < 33) return;
  lastFrame = millis();

  // Brightness mode is modal: freeze the page (the panel keeps the last frame)
  // and redraw the overlay only when the level changes -> no per-frame flicker.
  if (brightMode) {
    if (blLevel != lastShownLevel) { drawBrightnessOverlay(); lastShownLevel = blLevel; }
    return;
  }

  bool sOk = sessHave && !waiting, wOk = weekHave && !waiting, pOk = !waiting;
  // Usage went stale if the host says its last successful fetch is too old. -1 =
  // the host never reported an age (old host, or no success yet) -> don't gray.
  bool usageFresh = (usageAgeTarget < 0) || (usageAgeTarget <= USAGE_STALE_SEC);
  bool sFresh = sOk && usageFresh, wFresh = wOk && usageFresh;
  if (page == 0) {
    drawRing(OUT_R0, OUT_R1, cpuDisp, pOk ? zoneColor(cpuDisp) : GRAY);
    drawRing(IN_R0,  IN_R1,  ramDisp, pOk ? zoneColor(ramDisp) : GRAY);
    drawRing(TA_R0,  TA_R1,  sessDisp, sFresh ? zoneColor(sessDisp) : GRAY);
    drawRing(TB_R0,  TB_R1,  weekDisp, wFresh ? zoneColor(weekDisp) : GRAY);
    drawStartTick();
    drawCenter(waiting, "CPU", cpuDisp, true, "RAM", ramDisp, true,
               -1, -1, -1, -1, false, false, /*histKind=*/0);
  } else if (page == 1) {
    drawRing(OUT_R0, OUT_R1, sessDisp, sFresh ? zoneColor(sessDisp) : GRAY);
    drawRing(IN_R0,  IN_R1,  weekDisp, wFresh ? zoneColor(weekDisp) : GRAY);
    drawRing(TA_R0,  TA_R1,  cpuDisp,  pOk ? zoneColor(cpuDisp)  : GRAY);
    drawRing(TB_R0,  TB_R1,  ramDisp,  pOk ? zoneColor(ramDisp)  : GRAY);
    drawStartTick();
    if ((sOk || wOk) && !usageFresh) {
      // Usage frozen (dead token / rate-limit storm): show the last values gray
      // with an actionable amber hint -- opening Claude Code refreshes the token.
      char ageStr[16];
      int a = (int)usageAgeTarget;
      if (a < 5400) snprintf(ageStr, sizeof(ageStr), "STALE %dm", (a + 30) / 60);
      else          snprintf(ageStr, sizeof(ageStr), "STALE %dh", (a + 1800) / 3600);
      drawCenter(waiting, "SESSION", sessDisp, sOk, "WEEK", weekDisp, wOk,
                 -1, -1, -1, -1, true, true, /*histKind=*/-1,
                 "OPEN CLAUDE", ageStr);
    } else {
      drawCenter(waiting, "SESSION", sessDisp, sOk, "WEEK", weekDisp, wOk,
                 sOk ? sesspTarget : -1, wOk ? weekpTarget : -1,
                 sOk ? sesshVal : -1,    wOk ? weekhVal : -1,
                 sOk && !usageFresh, wOk && !usageFresh, /*histKind=*/1);
    }
  } else {
    // Page2: only the thin CPU/RAM rings (like the Claude-usage view); all the
    // freed space goes to a bigger top-7 process chart.
    drawRing(TA_R0, TA_R1, cpuDisp, pOk ? zoneColor(cpuDisp) : GRAY);
    drawRing(TB_R0, TB_R1, ramDisp, pOk ? zoneColor(ramDisp) : GRAY);
    drawChart(waiting);
  }
}

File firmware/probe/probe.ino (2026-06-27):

// Probe sketch for GUITION ESP32-2424S012 (ESP32-C3 + 1.28" round GC9A01 + CST816 touch)
// Goal: empirically confirm the documented pinout lights the screen.
//
// Pinout under test (from board docs):
//   LCD: SCLK=6  MOSI=7  DC=2  CS=10  RST=-1(none)  BL=3
//   Touch CST816 (I2C @0x15): SDA=4 SCL=5 INT=0 RST=1
//
// Build needs LovyanGFX. Serial uses USB CDC (FQBN flag CDCOnBoot=cdc).

#include <LovyanGFX.hpp>

class LGFX : public lgfx::LGFX_Device {
  lgfx::Panel_GC9A01 _panel;
  lgfx::Bus_SPI      _bus;
public:
  LGFX() {
    { auto c = _bus.config();
      c.spi_host   = SPI2_HOST;   // FSPI on the C3
      c.spi_mode   = 0;
      c.freq_write = 40000000;
      c.freq_read  = 16000000;
      c.pin_sclk   = 6;
      c.pin_mosi   = 7;
      c.pin_miso   = -1;
      c.pin_dc     = 2;
      _bus.config(c);
      _panel.setBus(&_bus);
    }
    { auto c = _panel.config();
      c.pin_cs   = 10;
      c.pin_rst  = -1;
      c.pin_busy = -1;
      c.panel_width   = 240;
      c.panel_height  = 240;
      c.offset_x = 0;
      c.offset_y = 0;
      c.readable   = false;
      c.invert     = true;   // GC9A01 wants inversion on
      c.rgb_order  = false;
      c.dlen_16bit = false;
      c.bus_shared = false;
      _panel.config(c);
    }
    setPanel(&_panel);
  }
};

LGFX tft;

static const int PIN_BL = 3;

void setup() {
  Serial.begin(115200);
  delay(300);
  Serial.println();
  Serial.println("=== ESP32-2424S012 PROBE ===");

  // Step 1: backlight test — blink 3x so you can see GPIO3 controls the panel light
  pinMode(PIN_BL, OUTPUT);
  for (int i = 0; i < 3; i++) {
    Serial.printf("backlight ON  (GPIO%d)\n", PIN_BL);
    digitalWrite(PIN_BL, HIGH); delay(350);
    Serial.println("backlight OFF");
    digitalWrite(PIN_BL, LOW);  delay(250);
  }
  digitalWrite(PIN_BL, HIGH);   // leave it on

  // Step 2: bring up the GC9A01
  Serial.println("init GC9A01...");
  tft.init();
  tft.setRotation(0);

  // color flood so you can confirm pixels are real
  tft.fillScreen(TFT_RED);   delay(400);
  tft.fillScreen(TFT_GREEN); delay(400);
  tft.fillScreen(TFT_BLUE);  delay(400);
  tft.fillScreen(TFT_BLACK);

  // centered round-display test pattern
  int cx = 120, cy = 120;
  for (int r = 118; r > 0; r -= 12)
    tft.drawCircle(cx, cy, r, tft.color565(0, 180, 255));
  tft.drawFastHLine(0, cy, 240, TFT_DARKGREY);
  tft.drawFastVLine(cx, 0, 240, TFT_DARKGREY);

  tft.setTextDatum(middle_center);
  tft.setTextColor(TFT_WHITE, TFT_BLACK);
  tft.setTextSize(2);
  tft.drawString("PROBE OK", cx, cy - 18);
  tft.setTextSize(1);
  tft.drawString("ESP32-2424S012", cx, cy + 12);
  tft.drawString("240x240 GC9A01", cx, cy + 30);

  Serial.println("display init done -> you should see 'PROBE OK'");
}

void loop() {
  // heartbeat: small sweeping arc + serial tick so we know it's alive
  static int a = 0;
  static uint32_t last = 0;
  if (millis() - last > 40) {
    last = millis();
    float rad = a * 3.14159265f / 180.0f;
    int x = 120 + (int)(60 * cosf(rad));
    int y = 120 + (int)(60 * sinf(rad));
    tft.fillCircle(x, y, 4, TFT_YELLOW);
    tft.fillCircle(120 + (int)(60 * cosf((a - 12) * 3.14159265f / 180.0f)),
                   120 + (int)(60 * sinf((a - 12) * 3.14159265f / 180.0f)), 4, TFT_BLACK);
    a = (a + 6) % 360;
    if (a == 0) Serial.println("alive");
  }
}

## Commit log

2026-06-27 Initial commit: roundtft PC + Claude usage monitor
    ESP32-2424S012 round display firmware (CPU/RAM + Claude session/week pages,
    touch paging + rotate, period-progress bars, start ticks), Windows host agent,
    3D tilt-stand (OpenSCAD), and docs.
    [stand.scad, stand.stl]
2026-06-27 Center period bars, hours-left labels; revert to direct-draw rendering
    - Firmware: render rings directly + small center sprite (full-screen sprite
    double-buffer blanked the panel); zero tick moved into the ring gap so it
    cannot flicker; SESS/WEEK page shows period-progress bars with hours-left,
    now centered as a bar+label group.
    - Host: send sessp/weekp (period elapsed %) and sessh/weekh (hours left).
    - Docs: CLAUDE.md gotchas (no full-screen double-buffer; tick in ring gap).
    [monitor.ino, pc_monitor.py]
2026-06-27 Add README; show "left" on Claude time-left labels
    - Claude page time labels now read "Nh left" / "Nd left" (centered with the bar).
    - Add repo README.md (project overview, hardware, build/flash, host, usage,
    3D stand) as the GitHub landing page.
2026-06-29 Add Windows autostart for the host monitor agent
    Register a hidden per-user scheduled task that launches pc_monitor.py at
    logon and restarts it on crash:
    - run-monitor-hidden.bat: windowless launch via pythonw, logs to LOCALAPPDATA
    - monitor-launch.vbs: runs the bat with no console flash
    - install-startup.ps1 / uninstall-startup.ps1: register/remove the task
    - CLAUDE.md: document the autostart chain and stop-before-flash step
2026-06-29 Docs: refresh host README for autostart + cable troubleshooting
    host/README.md described the old manual startup and a stale "add Claude
    usage later" TODO. Update it to:
    - note the device model (GUITION ESP32-2424S012) and that Claude usage ships
    - document the install/uninstall-startup.ps1 scheduled-task workflow
    - add troubleshooting for the charge-only-cable / "WAITING FOR PC" symptom
    Also point the top-level README at the autostart script.
2026-06-29 Lightweight host loop, 10s firmware hold, default rotation 3, robust autostart
    Host agent (pc_monitor.py): after an adversarial review confirmed the 1s loop is
    already CPU-light (cpu_percent sleeps; 5-min cache gates all net/file work), the
    one real cost was the per-second print appended forever to the autostart log.
    - Suppress the per-second data line when not on a console (cached None-safe TTY
    check); keep connect/error events. Off-console it self-opens the logfile.
    - Self-bootstrap the package dir (E:\dev\pip, override ROUNDTFT_PIP) so the task
    can run pythonw.exe directly with no PYTHONPATH.
    Autostart: launch pythonw.exe DIRECTLY instead of wscript->cmd->pythonw. The
    wrapper chain l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
    [monitor.ino, pc_monitor.py]
2026-06-30 Add Page 2: top-7 process memory/CPU bar chart
    Host (pc_monitor.py):
    - New "proc=" line with the top-7 processes by memory, gathered via a
    single NtQuerySystemInformation snapshot (~7ms, ~0 CPU) on a daemon
    thread, with a psutil OpenProcess fallback (~1s) that backs off if the
    native struct ever fails. Memory reported as working-set GiB (2 dp),
    CPU as share of the whole machine.
    Firmware (monitor.ino):
    - Third page (short tap now cycles 0/1/2) drawing a diverging "tornado"
    chart in a 154px sprite: memory grows left (cyan), CPU right (orange)
    from a central spine, process names float over the spine with a dark
    halo, GB and % labels sit in the outer gutters. Biggest-memory proce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
    [monitor.ino, pc_monitor.py]
2026-06-30 Add touch brightness control + persist brightness & orientation
    - Backlight (GPIO3) is now 5 kHz/8-bit LEDC PWM instead of digital-on,
    floored at ~5% so it never goes fully dark.
    - New gesture: hold past 1.5s enters brightness mode -- a vertical level
    bar overlays the current page and dragging up/down sets the backlight
    live. Rotate moved to release of a 0.6-1.5s hold so the two don't clash.
    - Overlay is modal: the page is frozen and the bar is only redrawn when
    the level changes, so it no longer flickers each frame.
    - Brightness and rotation persist to NVS flash (namespace "roundtft",
    keys "bl"/"rot") and are restored on boot; written only on change.
    - Touch reads now decode X/Y (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
    [monitor.ino]
2026-06-30 Page 2: longer left-aligned process names with a yellow divider
    - Names extended from 7 to 12 chars (host _san cap + wider firmware name
    buffer; serial line cap raised to 300 to fit the longer payload).
    - Names are now left-aligned in a fixed column instead of centered over
    the spine, sitting just past the GB memory labels.
    - A thin (1px) yellow vertical divider separates the GB memory column
    from the names; the column x is measured from the widest GB label so
    the line clears them all.
    [monitor.ino, pc_monitor.py]
2026-07-01 Debounce touch input to stop phantom page changes
    The CST816 FingerNum register was polled over I2C every loop iteration
    without gating on the INT line, so an occasional read landed mid-update
    and returned a phantom finger-down (and a dropped read during a real
    touch returned a phantom up). With no debouncing, either single-sample
    glitch became a down->up edge that the release handler read as a short
    tap -> the page advanced with nothing touching the screen.
    Require the raw reading to hold steady for 40ms before the debounced
    state flips, so one-sample glitches never form an edge. Real taps
    (60-200ms) pass unchanged, and since both press and release edges shift
    by the same ~40ms the tap/rot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
    [monitor.ino]
2026-07-02 Stop autonomous phantom page flips; keep backlight readable
    The panel flipped pages by itself, worse right after a rotate. Investigated
    on-device with serial captures: the CST816 genuinely self-reports touches
    (status=0x01 + real INT) clustered at screen-center with jitter -- not a
    finger. Long hands-off, self-cycling diagnostics RULED OUT backlight-PWM
    coupling, display-redraw noise, and auto-sleep wake transients as autonomous
    triggers; the phantoms only ever appeared when the panel was left unpolled
    while idle, consistent with a prolonged touch (rotate/brightness hold)
    poisoning the controller's baseline and a burst firing as it re-converges.
    Fixes:
    - Poll the touch controller every loop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
    [monitor.ino]
2026-07-02 Add swipe-to-rotate gesture, replacing hold-to-rotate
    Orientation was changed by a 0.6-1.5s hold -- a fragile timing band, and the
    prolonged touch that poisons the CST816 baseline and triggers the post-rotate
    phantom-flip bursts. Replace it with a horizontal swipe:
    - readTouchY -> readTouch(sx,sy): map the point to on-screen coords on both axes
    (was vertical-only) so "horizontal" means the same to the user in any rotation.
    - Track the press-edge origin; at release, net horizontal travel >= SWIPE_MIN_PX
    (and |dx|>|dy|) rotates 90 deg -- right = CW, left = CCW (one-line flip constant).
    - Gesture ladder is now: swipe = rotate, tap = next page, hold >1.5s = brightness.
    The 0.6-1.5s rotate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
    [monitor.ino]
2026-07-02 Rotate on a swipe in any direction, not just horizontal
    On-device trajectory capture showed the CST816 tracks swipe motion cleanly, but
    users naturally swipe vertically as often as horizontally -- and horizontal-only
    detection dropped those to page-changes ("hard to get the swipe to register").
    Accept a swipe on either axis (|dx| or |dy| >= SWIPE_MIN_PX); the dominant axis's
    sign picks CW vs CCW (SWIPE_CW flips all directions). Measured separation is wide:
    real swipes travel 150-200px, taps 0-8px, phantom peaks ~40px, bar is 50px.
    Also removes the trajectory/gesture-register diagnostics used to find this.
    Confirmed working on-device.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
    [monitor.ino]
2026-07-03 Retry Claude usage fetches fast instead of blanking for 5 minutes
    The usage rings went blank whenever the OAuth usage endpoint returned
    429 (rate-limited) or 401 (token mid-rotation): get_claude_usage()
    cached every result -- success or failure -- for USAGE_REFRESH (5 min),
    so a single rejected slot dropped sess=/week= from the line for the whole
    window and the firmware greyed the rings. A fresh process that started
    during a rate-limited stretch never populated at all.
    Split the cache timing: keep 5 min after a success, but retry after
    USAGE_RETRY (30 s) on failure, honoring a 429 Retry-After header (capped
    at USAGE_RETRY_MAX). Last-known values are retained across failures, so a
    transient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
    [pc_monitor.py]
2026-07-03 De-noise the host log: timestamps + log board absence once per outage
    The monitor logged "board not found (303A:1001); retrying..." every 2 s
    for the whole duration of an outage, so a single ~4.4 h disconnect wrote
    7,880 identical lines -- 9,486 in total across the log -- which read as
    chronic USB flapping when it was really just 5 discrete outages (mostly
    the board unplugged during dev while the task kept running).
    - Add a timestamped _log() and route all connect/disconnect/error/usage
    events through it, so events can be correlated with reboots/unplugs.
    - Log "board not found" once when the board goes absent, not every retry;
    the reconnect line then reports how long it was gone ("was a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
    [pc_monitor.py]
2026-07-06 Gray the Claude usage readout when it goes stale
    The usage endpoint intermittently 429-storms for hours, during which
    get_claude_usage() serves its last-good cache and the host keeps streaming
    the same sess/week -- so the display showed a frozen number in normal color
    with no hint it was stale (the firmware "waiting" signal never trips because
    per-second cpu/ram keep lastData fresh).
    Host: emit usageage=<sec since last *successful* fetch>, and log a one-line
    recovery message after a run of failures (mirrors the board "was absent Ns"
    de-noising) so future storms are legible in the log.
    Firmware: gray the session/week number and rings (keeping the last value
    visible) once usageage exceeds 90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
    [monitor.ino, pc_monitor.py]
2026-07-07 Poll Claude usage gently to survive the endpoint's tight rate limit
    The oauth/usage endpoint is aggressively rate-limited per token (~5 requests
    trip a 429 with Retry-After 300), and that budget is shared with Claude Code's
    own usage polling. The old "retry fast so the display doesn't blank" design was
    the cause of the outages, not a mitigation: on a token rotation the 401s drove a
    30s retry burst that tripped the 429, then the 300s polling kept it perpetually
    tripped -- hours with no successful fetch.
    Stop competing with the limit:
    - 15-min success cadence (was 5) to leave headroom for Claude Code.
    - On 401, wait for Claude Code to rotate accessToken (cheap file re-reads only,
    no network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
    [pc_monitor.py]
2026-07-08 Add a faint history backdrop behind the CPU/RAM and usage readouts
    Page 0 and page 1 now show recent history as a dim (~22%) zone-heat
    graph inside the center sprite -- top metric in the top half, bottom
    metric in the bottom, newest column at the right -- with the numbers
    redrawn on a transparent bg (1px dark halo) so they stay crisp on top.
    Data is built entirely on-device (no host/protocol change): CPU/RAM
    push one sample per data line (~1/s, ~1.7 min span); session/week
    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
2026-07-09 Stop ghost touches: don't let a blocking serial write freeze the touch poll
    The "ghost" taps/holds were never a display or CST816 defect. The host agent
    (pc_monitor.py) holds the USB-CDC port open but only ever writes to it -- it
    never reads the device's output. On the ESP32-C3's native USB-Serial-JTAG, an
    un-drained TX FIFO makes Serial.printf BLOCK the main loop until it can flush.
    Every gesture prints (page/swipe/brightness), so each gesture stalled the loop
    for ~2 s. During that stall handleTouch() never ran, the CST816 went unpolled,
    and the unpolled controller emitted a burst of phantom center-touches that the
    resumed loop read as ghost taps/holds. This exactly matches the old symptom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
    [monitor.ino]
2026-07-10 Drop the 2s post-hold lockout that only masked the serial-stall phantoms
    With the blocking-printf root cause fixed (Serial.setTxTimeoutMs(0)), the
    CST816 stays polled through every gesture, so there is no phantom burst left
    to swallow. ROT_LOCK_MS (2000ms after a brightness hold) was a band-aid sized
    to that ~2068ms stall -- now dead weight, and a 2s dead window after every
    brightness adjustment.
    Collapse to a single 150ms GESTURE_LOCK_MS after any gesture, which still
    covers the real, independent lift-off re-graze on the convex round glass.
    Keep the 40ms debounce (guards single-sample I2C read glitches) and rewrite
    the comments that blamed "baseline re-converging"/"idle polling" -- that wa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
    [monitor.ino]
2026-07-15 Show an actionable "OPEN CLAUDE / STALE Nh" hint when usage freezes
    When Claude Code isn't running to refresh the OAuth token, the host's usage
    probes fail (401 dead-token + 429 rate-limit storm) and the SESSION/WEEK
    readout just grayed out with no explanation -- the "usage gone for ages" case.
    The host can't refresh the token itself without risking Claude Code's own
    login (refresh-token rotation), so instead of fixing the token flow, make the
    grayed-out state actionable: on the usage page, once usage is stale (>15 min
    since a good fetch) the center now shows the last values in gray plus an amber
    OPEN CLAUDE / STALE Nh hint. Opening Claude Code refreshes the token and the
    board recovers --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
    [monitor.ino]
2026-07-16 Refresh the OAuth token ourselves so usage survives Claude Code being closed
    The usage readout kept going blank for a day at a time. Root cause was never the
    rate limiting we kept chasing: accessToken lives ~8 h and Claude Code alone
    refreshes it, so an idle day left the monitor 401ing until the user next opened
    Claude Code. The interleaved 429s were just the endpoint throttling dead-token
    retries -- a symptom we had mistaken for the disease, and previously papered over
    by graying the value and showing an "OPEN CLAUDE" hint.
    Run the standard refresh_token grant ourselves instead, against the same endpoint
    and client id Claude Code uses. Usage is now bounded by refreshTokenExpiresAt
    (~9 days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
    [pc_monitor.py]
2026-08-13 Refit the stand for the shelled unit: 11 mm pebble, side USB-C exit
    The stand was cut for a bare 40.5 x 4.6 mm PCB. The unit is staying in its
    plastic shell, which is a rounded pebble: 40.5 mm at the equator, 11 mm
    thick, domed glass, USB-C on the rim.
    Seat is a straight bore + front lip. A conical seat was tried first and
    dropped -- where a cone grips depends on the rim's curvature, which can't be
    measured off a photo, whereas the lip stops the shell in the same place
    whatever the rim does. Gravity (the 20 deg lean) holds it on the lip, so
    nothing snaps or clamps and it still lifts out; ~2 mm of shell stands proud
    at the back to push on.
    USB-C now exits sideways rather than down: a right-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
    [stand.scad, stand.stl]
2026-08-13 Add a self-contained drawing sheet for the stand
    drawing.html is a drafting sheet for the cradle: a dimensioned section through
    the seat drawn from the actual stand.scad parameters (so it shows how the front
    lip catches the shell, not just a pretty render), the five views, the dimension
    schedule with what is measured vs still to verify, and the fit-check numbers.
    Self-contained is a hard requirement, not a preference -- the page publishes as
    an Artifact and that CSP blocks every external host, so all ten views are
    inlined as base64. Each view is rendered on both a light and a dark ground and
    swapped with the viewer's theme.
    build_page.py renders the views and inlines them, so the sheet reg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
2026-08-13 Lay the cradle back to 38 deg, and fix the base plate floating off the bed
    The 20 deg lean stood the screen too upright. tilt is now 38 deg, which aims
    the screen's normal at a seated viewer roughly 1.4x as far away as they are
    above it. Height drops 51.9 -> 47.0 mm.
    place_z is now DERIVED from tilt rather than hard-coded. Leaning the cradle
    moves its lowest edge, so a typed-in height silently goes wrong the moment the
    stance changes -- which is how the part previously ended up 1.3 mm under the
    build plate. Change tilt alone and the geometry follows.
    Checking the new stance turned up a fault that long predates it: base_plate()
    lifted the slab by base_t/2 as though rrect() were centred on t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
    [stand.scad, stand.stl]
2026-08-13 Add stand.3mf and a measured printability check for the K1 Max
    3MF rather than STL is what to load: it carries units, so it imports at the
    right size and orientation instead of relying on the slicer guessing mm.
    print_check.py answers the questions a slicer preview would, but numerically --
    build-volume fit, downward-facing area bucketed by lean from vertical, and how
    much of the base actually touches the bed. On the K1 Max the part uses 21% of
    the build volume and makes 3182 mm^2 of bed contact.
    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
    [stand.3mf]
2026-08-13 Draw what to measure, rather than describing it in prose
    The one unverified dimension is the shell's glass diameter, and "the lip must
    land on the plastic rim, not the glass" is easy to misread as a sentence. So the
    sheet now shows it: a front view with the calipers drawn across the glass, and
    two cross-sections contrasting a lip that lands on the rim with one that perches
    on the dome and rocks.
    Adds the plug-width check too -- the rim notch is 16 mm and a right-angle plug's
    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
2026-08-13 Resize for the real shell: 45 mm outer, 42 mm glass
    The 40.5 mm outer diameter was wrong. Measured off the shell it is 45 mm, with
    a 42 mm glass -- so the glass alone is larger than the diameter the whole cradle
    had been built around, and the old 38.0 lip bore would have closed 2 mm over the
    screen on every side.
    That leaves 1.5 mm of plastic rim to land on, which is now the tightest fit in
    the part. aperture = 43.0 splits it: 0.5 mm clear of the glass, 1.0 mm of ledge
    under the shell. The clearance goes on the glass side because FDM prints holes
    undersize -- a lip that comes out 0.3 mm tight still holds, a lip that creeps
    onto the domed glass makes the shell rock.
    Since two size errors in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
    [stand.3mf, stand.scad, stand.stl]
2026-08-13 Confirm disc_t at 11 mm - the seat is now fully measured
    Re-checked after the diameter correction, since it came from the same session
    as the wrong 40.5. It was already 11 in the model, so no geometry changes.
    That clears the last estimated dimension in the seat: disc_d 45, glass_d 42 and
    disc_t 11 are all measured. The only guessed number left anywhere is rim_r,
    which exists inside the fit-check stand-in and never reaches the printed part.
2026-08-13 Regenerate the print model - final, all dimensions confirmed
    stand.3mf rebuilt from source with every seat dimension measured. Validated the
    container rather than assuming it: zip intact, unit attribute reads
    "millimeter", 3098 triangles, bbox 58.00 x 69.73 x 50.58 sitting on z = 0. A
    wrong unit would import at the wrong scale and look plausible doing it.
    Final verification: interference 0.00 mm^3, single body, bed contact 3121.40 vs
    3121.55 predicted for an intact footprint, 46 mm^2 of overhang past 55 deg.
    Plug body confirmed under 15 mm, so the 16 mm rim notch stands.
    [stand.3mf, stand.stl]
2026-08-14 Adversarial review: fix an impossible shell model and a bore that could not be assembled
    Reviewed against the fact that this is a stock display, looking for numbers that
    are not what a standard part would be.
    rim_r contradicted the measurements. The fit-check stand-in used an eyeballed
    3.5 mm edge radius, which implies a 38 mm front face -- too small to carry the
    measured 42 mm glass. Every interference check to date had been run against a
    shape that cannot exist. It is now derived as (disc_d - glass_d)/2 = 1.5, which
    is the geometric bound: the glass sits on the front face, so the face cannot be
    smaller than the glass. Re-verified at 0.00 mm^3; the shell actually stands
    2.71 mm proud, not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
    [stand.3mf, stand.scad, stand.stl]
2026-08-14 Cross-check the fit against the published ESP32-2424S012C specs
    Looked up what a stock unit actually measures rather than trusting the caliper
    readings alone: bare PCB 38.5 x 37.0, active display 32.4 dia, panel outline
    ~35.6 x 38.1, cased diameter "about 42 mm" (CNX Software).
    Two things fall out.
    active_d = 32.4 is the only dimension that cannot vary between units or be
    mismeasured, which makes it the one backstop that survives a bad reading on
    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
    [stand.3mf, stand.scad, stand.stl]
2026-08-14 Add sliced K1 Max G-code, and the profiles that produced it
    No slicer existed on this machine, so this pulls OrcaSlicer 2.4.2 portable and
    slices against Creality's own "K1 Max (0.4 nozzle)" machine profile. That matters
    more than the settings: it means the start macro is the real Klipper one,
    START_PRINT EXTRUDER_TEMP=200 BED_TEMP=45, rather than something hand-authored
    that could drive the nozzle into the plate.
    59m17s, 24.8 g, 253 layers.
    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
    [machine.json, stand.3mf, stand.stl]
2026-08-14 Commit the verification tooling, and fix the non-manifold edges it found
    The README has been telling you to re-run the interference and bed-contact
    checks for several commits, but those scripts only ever existed in a scratch
    directory. They are now in the repo as verify.py + verify.scad, consolidated
    into ten pass/fail checks rather than four loose files.
    Running it on the current model immediately failed one: 4 non-manifold edges.
    Locating them rather than guessing put all four at the top of the back leg,
    where the neck stub started at z=0 -- exactly coplanar with the ring's front
    face, so four faces met along each edge. The stub is now inset 0.6 mm from both
    ring faces and the mesh is cle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
    [stand.3mf, stand.scad, stand.stl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]
2026-08-17 Fix the bed adhesion: brim, and the 45 C bed that was the real fault
    The first print came off the plate. The missing brim was the visible half.
    The other half: filament.json inherits the GENERIC pla library profile, which
    runs textured PEI at 45 C with a 200 C nozzle -- Creality's own PLA is 60/220.
    A 45 C plate barely holds PLA, and with close_fan_the_first_x_layers at 1 the
    K1's part fan hits 100% on layer 2 and peels the corners while the plate is
    still weak. None of that is visible in a slicer UI, only in the G-code.
    Now: 8 mm outer brim at gap 0, 60 C bed, 215/210 nozzle, fan off for 3 layers,
    first layer 0.25 mm at 30 mm/s. Costs ~3 min and 0.4 g.
    outer_brim_only is not a value Orca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
    [stand_K1Max_project.3mf]
2026-08-17 Save the project 3mf back from the slicer, with supports enabled
    Opened in Creality's slicer (02.06.00.51) and re-saved: it adds plate
    thumbnails, fills in the newer version's filament keys, and stamps the preset
    names with the project file.
    The one real change is enable_support 0 -> 1, which the file records itself in
    different_settings_to_system. Geometry is untouched -- identity placement
    matrix, and the slicer's own mesh_stat repaired nothing (edges_fixed 0,
    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
    [stand_K1Max_project.3mf]
